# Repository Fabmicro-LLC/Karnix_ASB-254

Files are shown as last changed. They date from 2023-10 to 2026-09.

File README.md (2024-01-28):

# Karnaugh Interactive Extendable ASIC Simulation Board AKA Karnix ASB-254.

## Features:

- RPi3 form factor board with 40pin head connector
- Lattice ECP5 25K FPGA, RISC-V ready
- SRAM 16x256 KBits (512 KB)
- NOR flash 128 MBits for FPGA configs
- EEPROM 1Kbits (128 bytes) for user settings
- Ethernet 10/100Base-TX
- RS-485 transceiver
- HDMI connector directly connected to FPGA
- SPI DAC 4 channels (2 for audio)
- SPI ADC 4 channels + 1 mic in
- 4 keys and 4 LEDs
- 4 pin audio jack connected to DAC/ADC
- Built-in FT2232D based programmer

## Board images

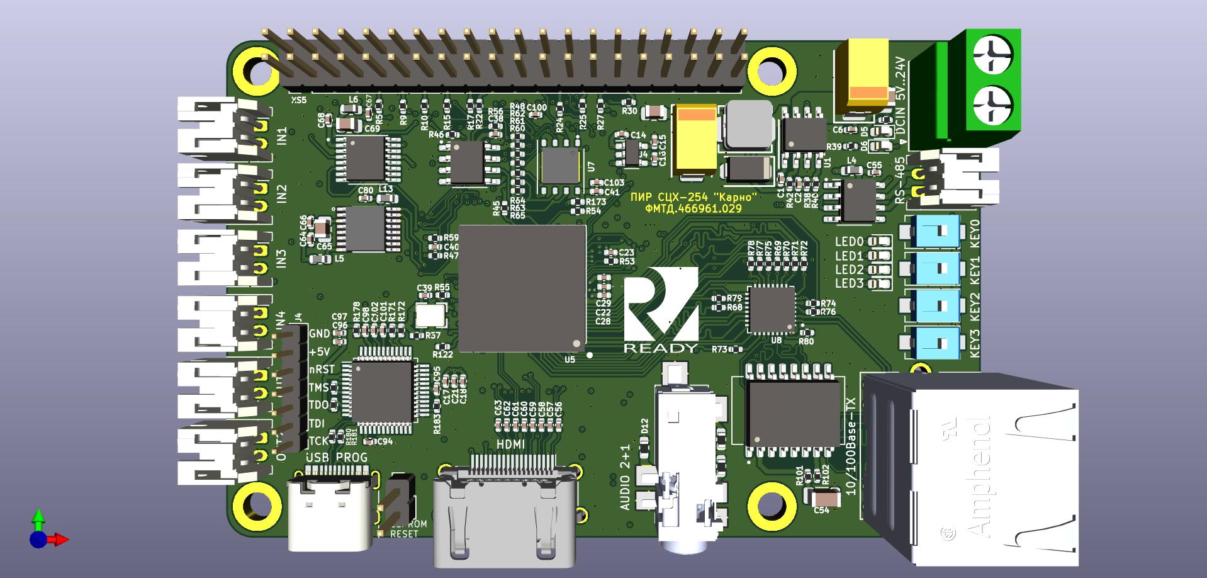
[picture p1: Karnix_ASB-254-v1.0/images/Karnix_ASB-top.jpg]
TOP side


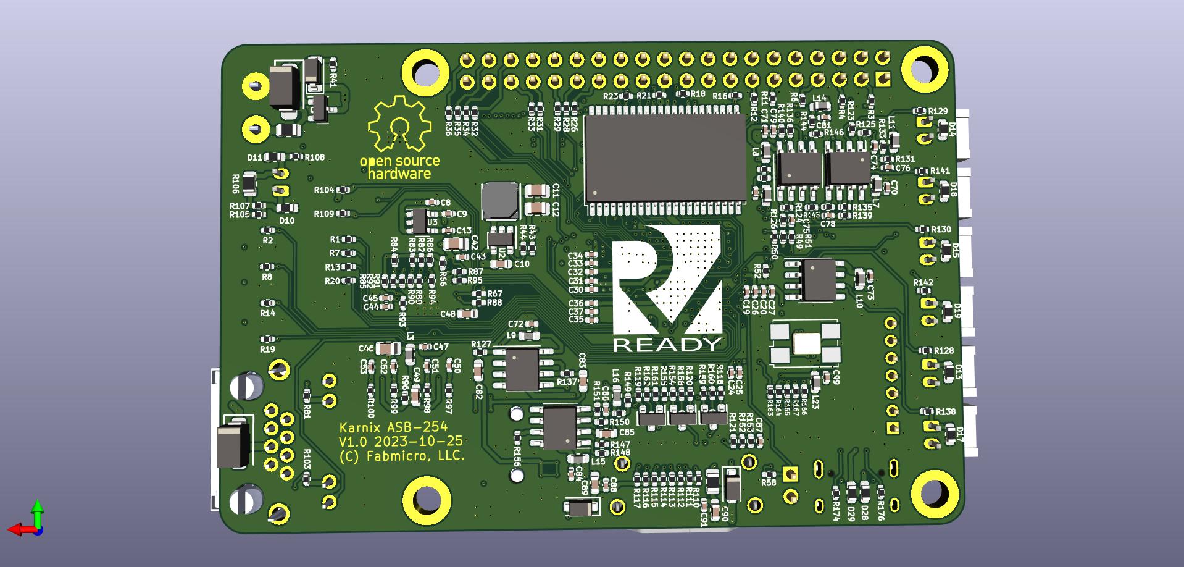
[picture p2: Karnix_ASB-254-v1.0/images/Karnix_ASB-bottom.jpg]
BOTTOM side


# Karnix v1.0 bugs

Version 1.0 appeared to be buggy:
- Ethernet does not work because of wrong power wiring.
- FT2232D IOVCC was wrongly wired to +5V instead of +3V3.
- Some issues with footprints.

## Examples

- Directory **Examples/VexRiscvWithHUB12ForKarnix** contains complete implementation of HUB-12/HUB-75 adapter for LED matrixes written in C running on VexRiscv soft-core. It provides Modbus/UDP interface to corresponding LED matrix.

## Video

https://www.youtube.com/watch?v=xr0pdGuJbXQ

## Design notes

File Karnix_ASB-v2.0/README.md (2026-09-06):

2026-09-01 (DONE)
=================

1. Сократить число портов АЦП и ЦАП до 2+2 (плюс аудио).
2. Сагрегировать линии ЦАП и АЦП каждый в своем идином ращъеме JST 4пин.
3. Добавить тактовый сигнал для NOR Flash памяти.
4. Добавить разъем SD-карты (режим SPI).
5. Перенести кнопки в другое место, высвободить место под USB type A.
6. Добавить USB type A.
7. Добавить SDRAM 64МБ.
8. (-) Добавить сигнал LDAC на ЦАП.

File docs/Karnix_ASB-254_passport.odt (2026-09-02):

Плата разработчика

ПИР СЦХ-254 «КАРНО»

ФМТД.466961.029

вер. 1.x

ПАСПОРТ

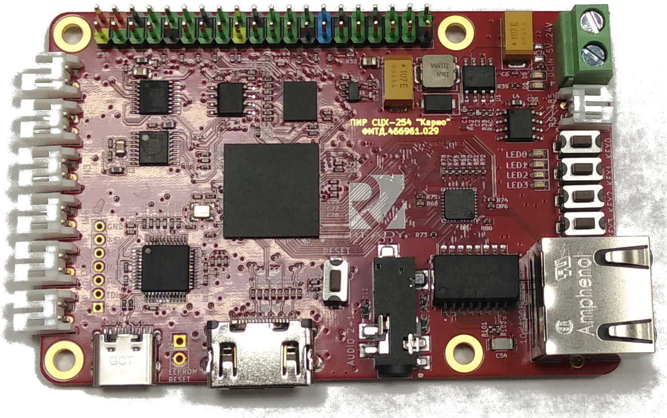
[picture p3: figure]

1. НАЗНАЧЕНИЕ

Плата разработчика "Карно" спроектрована на основе микросхемы ПЛИС Lattice ECP5 и предназначена для синтеза цифровых схем и их тестирования. На плате может быть собран полноценный микроконтроллер для управления промышленными устройствами.

В качестве демонстрации мы синтезировали средствами ПЛИС полноценный микроконтроллер с вычислительным ядром RISC-V (VexRiscV с тактовой частотой 60 МГц), контроллером FastEthernet и контроллером интерфейса HUB75. Через HUB75 к плате может быть подключена светодиодная матрица формата 80x40 (RGB). На ядре RISC-V запускается программное обеспечение реализующее программный протокол Modbus over IP/UDP Modbus/UDP), через который ножно обновлять изображение выводимое на светодиодную матрицу, а также выводить данные на каналы АЦП, т.е. генерировать звук.

Плата ПИР СЦХ-254 "Карно" спроектированная в САПР KiCAD 7 и является полностью открытым проектом (OSHW). Цифровая аппаратура ПЛИС разработана на языке SpinalHDL и синтезирована с помощью open source toolchain Yosis / NextPNR. Программное опеспечения для ядра RISC-V написано на языке C с использованием облегченного TCP/IP стека lwIP. Объём машинного кода - 75КБ, размещается в синтезируемой RAM.

По способу защиты человека от поражения электрическим током плата разработчика «Карно» соответствуют классу III ГОСТ12.2.007.0-75 (сверхнизкое напряжение).

По рабочим условиям применения (в части климатических и механических воздействий) плата разработчика «Карно» удовлетворяет требованиям групп исполнений В4 и L3 ГОСТ12997-84 соответственно.

Конструктивно, плата разработчика «Карно» выполнена в виде печатной платы с четырьмя монтажными отверстиями, предназначенные для монтажа в составе другого изделия или комплекса, по периметру платы располагаются интерфейсные разъемы.

Плата разработчика ПИР СЦХ-254 «Карно» поставляется БЕЗ программного обеспечения.

Ссылки на ресурсы в сети Интернет:

Схема и трассировка платы в САПР KiCAD:

https://github.com/Fabmicro-LLC/Karnix_ASB-254

Демонстрационное программное обеспечение:

https://github.com/Fabmicro-LLC/VexRiscvWithHUB12ForKarnix

Демонстрационное видео:

https://www.youtube.com/watch?v=xr0pdGuJbXQ

2. ТЕХНИЧЕСКИЕ ХАРАКТЕРИСТИКИ

Таблица 1. Технические характеристики

Характеристики вычислительной системы:
Микросхема ПЛИС | Lattice ECP5 25К LUs
Количество вычислительных ядер: | 1
Тактовая частота: | 1028МГц
ОЗУ | 16x256 КБит (512 KБ)
ЭППЗУ | 1кБит
Объем NOR flash | 128МБит
Количество каналов АЦП, разрядность, тип | 5, 12 бит, SPI
Количество каналов ЦАП, разрядность, тип | 4, 12 бит, SPI
Сеть: - FastEthernet - UART | 10/100BaseT RS-485
Число дискретных линий ввода/вывода | 28
Тип дискретных линий ввода/вывода | LVCMOS33
Число кнопок | 4
Число светодиодных индикаторов | 4
Видео | HDMI, прямое соединение с ПЛИС
Аудио | 3.5`` Jack
Электропитание:
Напряжение питания на входе XS1: Напряжение питания на RJ-45 (passive PoE) Напряжение питания на разъеме программатора (USB) | 5 – 24В 5 – 24В 5,5В
Потребляемая мощность: | не более 2Вт
Условия эксплуатации:
Температура: | -40C / +45С
Влажность, не более | 85% при 35С
Габариты - печатной платы - печатной платы с разъемами | 85x56 мм 90x58 мм
Средний срок службы: | 10 лет
Время наработки на отказ: | 10000 часов
Программатор
Встроенный на базе FT2232D - канал 0 - канал 1 | JTAG UART
Интерфейс программатора | USB type C

3. ОРГАНЫ ИНДИКАЦИИ И УПРАВЛЕНИЯ

Плата разработчика ПИР СЦХ-254 «Карно» оснащена двумя светодиодными индикаторами зеленого цвета для индикации состояния линий питания питания и четырьмя светодиодными индикаторами LED0-LED3 зеленого цвета предназначенных для программирования пользователем.

На плате имеется одна кнопка системного сброса «RESET», нажатие на которую приводит к сбросу микросхемы ПЛИС и инициации процесса считывания конфигурации из NOR flash памяти, а так же четыре кнопки KEY0-KEY3 назначение которых определяется пользователем.

4. НАЗНАЧЕНИЕ РАЗЪЕМОВ

Подключение питания, внешних устройств к плате ПИР СЦХ-254 «Карно» осуществляется с помощью разъемов расположенных по периметру платы назначение которых приведено в таблице 2. Ниже приведено схематичное расположение разъемов и их обозначения (вид со строны «TOP»).

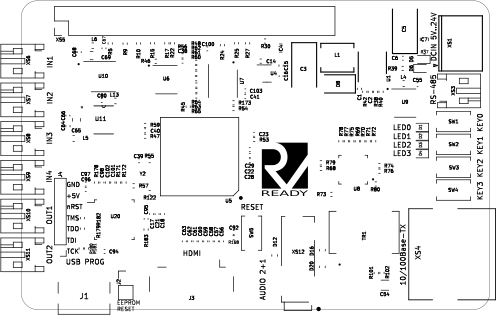
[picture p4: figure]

Рис. 1. Расположение разъемов и их обозначения.

Таблица 2. Назначение разъемов.

Обозначение на плате | Назначение и распиновка разъема
XS1 | Вход питания. Пин 1 — 5-24В, пин 2 — GND.
XS3 | RS-485. Пин 1 — линия А, пин 2 — линия B.
XS6 | Вход АЦП канала 1. Пин 1 — вход (макс 3.3В), пин 2 — GND.
XS7 | Вход АЦП канала 2. Пин 1 — вход (макс 3.3В), пин 2 — GND.
XS8 | Вход АЦП канала 3. Пин 1 — вход (макс 3.3В), пин 2 — GND.
XS9 | Вход АЦП канала 4. Пин 1 — вход (макс 3.3В), пин 2 — GND.
XS10 | Выход ЦАП канала 1. Пин 1 — выход (макс 3.3В), пин 2 — GND.
XS11 | Выход ЦАП канала 2. Пин 1 — выход (макс 3.3В), пин 2 — GND.
XS12 | Аудио вход/выход. Пин 1 — аудио левый канал (ЦАП канал 3) Пин 2 — аудио правый канал (ЦАП канал 4) Пин 3 — аудио вход (АЦП канал 5) Пин 4 — общий (GND).
XS4 | FastEthernet с фукцией passive PoE (пины 4 и 5 - «+», пины 7 и 8 - «-»).
XS5 | Разъем GPIO. Пин 1 и 17 - +3,3В Пин 2 - +5В Пин 6, 9, 14, 20, 25, 30, 34, 39 - «замля» (GND) Остальные пины — линии GPIO, уровень: 3.3В см. схему на рис. 2.
J3 | HDMI, прямое подключение к ПЛИС.
J1 | Разъем программирования через встроенный JTAG программатор (FT2232D)
J4 | Разъем прямого программирования ПЛИС через JTAG. Пин 1 — TCK Пин 2 — TDI Пин 3 — TDO Пин 4 — TMS Пин 5 — RESET Пин 6 — Питание +5В Пин 7 — общий (GND)

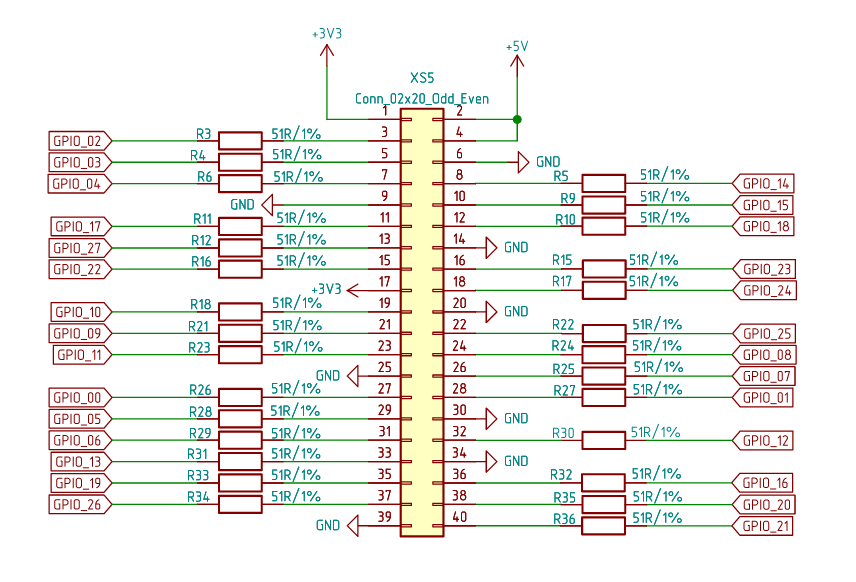
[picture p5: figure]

Рис. 2. Схема цоколевки разъема XS5.

5. КОМПЛЕКТНОСТЬ

Состав комплекта | Количество, шт.
Плата ПИР СЦХ-254 «Карно» | 1
Провод для программирования USB type C | 1
Паспорт | 1

6. УКАЗАНИЯ МЕР БЕЗОПАСНОСТИ
  1. Все отключения или подключения к плате должны осуществляться при выключенных источниках питания с соблюдением полярности.
  2. При эксплуатации платы должны выполняться требования техники безопасности, изложенные в документации на первичные преобразователи, средства измерений и оборудование, в комплекте с которыми она работает.
  1. Изделие имеет открытые низковольтные токоведущие части, попадание влаги или загрязнений в которые может привести к короткому замыканию и повреждению изделия.
7. ПРАВИЛА ТРАНСПОРТИРОВАНИЯ И ХРАНЕНИЯ

1) Изделие должно транспортироваться в условиях, не превышающих заданных предельных условий:

- температура окружающего воздуха -55 …+80 °С;

- относительная влажность воздуха до 95 % при температуре +35 °С.

2) Изделие может транспортироваться авиационным, железнодорожным или автомобильным видами транспорта в транспортной таре при условии защиты от прямого воздействия атмосферных осадков. Не допускается бросание изделия, изгибания или применение торсионной нагрузки.

3) Долгосрочное хранение изделия должно производиться в складских помещениях потребителя и поставщика в следующих условиях:

- температура окружающего воздуха 0 …+50 °С;

- относительная влажность воздуха до 95 % при температуре +35 °С.

- воздух помещения не должен содержать пыли, паров кислот и щелочей, а также газов, вызывающих коррозию.

8. ГАРАНТИЙНЫЕ ОБЯЗАТЕЛЬСТВА

1) Предприятие-изготовитель гарантирует соответствие выпускаемых изделий всем требованиям ТУ на них при соблюдении потребителем условий эксплуатации, транспортирования и хранения.

2) Длительность гарантийного срока устанавливается равной 12 месяцев.

3) Гарантийный срок исчисляется с даты отгрузки (продажи) изделия. Документом, подтверждающим гарантию, является паспорт с отметкой предприятия-изготовителя.

4) Гарантийный срок продлевается на время подачи и рассмотрения рекламации, а также на время проведения гарантийного ремонта силами изготовителя в период гарантийного срока.

9. КОНТАКТЫ ПРОИЗВОДИТЕЛЯ

ООО "Фабмикро"

625048, г. Тюмень, ул. Фабричная, д. 9/5, Российская Федерация.

Тел: +7-3452-591895, info@fabmicro.ru, https://www.fabmicro.ru

10. ОТМЕТКА О ПРОДАЖЕ

Сер. №: _____________, Дата: ______________

Продавец: ____________________ М.П.

____________________________________________________________ ПИР СЦХ-254 “КАРНО” вер. 1.x. Паспорт. Редакция от 03.02.2024 12

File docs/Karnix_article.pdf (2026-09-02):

## Отладочная плата ПИР СЦХ-254 «Карно»

Графов М.В., преподаватель НИУ «МЭИ» ведущий Школы Синтеза Цифровых Схем (https://engineer.yadro.com/chip-design-school/) в кластере «МЭИ» GrafovMV@mpei.ru

Аннотация
Статья посвящена краткому обзору аппаратных средств отладочной платы разработчика «Карно» [1] на базе FPGA серии ECP5 от Lattice Semiconductor, отечественного производителя ООО «Фабмикро» [2]. Рассмотрен состав платы, некоторые схемотехнические особенности, описан, обнаруженный в ходе работы над статьей, схемотехнический недостаток. В конце статьи приведены краткие выводы по возможностям платы, возможные области применения, выявленные достоинства и недостатки, а также полезные ссылки для дальнейшей самостоятельной работы специалистов и начинающих, заинтересованных в использовании данной платы. Введение
Отладочные платы для инженеров, связанных с разработкой устройств на базе FPGA или микроконтроллеров, чаще всего применяются в двух случаях: для начального изучения, используемой на плате FPGA или микроконтроллера, либо для быстрой реализации конкретного проекта, при условии наличия на плате необходимых аппаратных средств. В любом из этих случаев, использование готовых, отладочных плат значительно экономит время и силы, позволяя сконцентрироваться на изучении, либо на разработке текущего проекта, нежели, чем на разработку и сборку самой отладочной платы!
От проприетарного ПО к open source toolchain и Open-source hardware
В случае выбора пути покупки готовой платы, встаёт вопрос предпочтения, той или иной плате из набора существующих на рынке плат, приобретения отладочной платы, и собственно, эксплуатация платы, чему, в свою очередь, может значительно помочь техническая поддержка производителем. Обычно, техническая поддержка заключается в предоставлении производителем примеров кода для периферийных устройств, установленных на плате, документов с описанием портов ввода - вывода GPIO, а также с принципиальной схемой устройства.
На сегодняшний день на рынке предлагается большое количество таких изделий различных производителей и для большого количества микросхем программируемой логики, начиная от простых CPLD и заканчивая сложными FPGA большой ёмкости и SoC. Все они имеют очень разный набор периферийных средств, выпускаются разными производителями, но в подавляющем большинстве случаев их объединяет одно – необходимость наличия проприетарного программного обеспечения! Это значит, что формирующим bit-stream файл для целевой ПЛИС, должен быть софт от производителя самой ПЛИС! Да, бесспорным является тот факт, что существуют бесплатные версии IDE, поддерживающие ограниченный функционал и набор микросхем. Существуют сторонние редакторы HDL и различные вспомогательные программы, приложения, плагины и т.д., но… Как было сказано выше: «…конечным инструментом..» и т.д.! Хорошо это или плохо, вопрос не в этом, но это факт и его никак не оспорить! Ибо внутренняя структура микросхем ПЛИС известна только производителю этой микросхемы, а значит и софт должен быть только этого производителя! Однако, идеология open source не обошла и такую консервативную и закрытую тему, как ПЛИС и существует, как минимум один, производитель микросхем программируемой логики, с (условно) открытой архитектурой и также существует открытое ПО для таких микросхем. Речь идёт о производителе Lattice Semiconductor и открытом программном продукте (open source toolchain) Yosys. На этом месте необходимо сделать небольшой экскурс в историю, что бы понять смысл "условно" открытой архитектуры. Изделия фирмы Lattice, также, проприетарные и внутренняя их структура до недавнего времени была закрыта. Однако, в середине 2010-х небольшая группа исследователей из Германии смогла осуществить "реверс-инжениринг" некоторых из них - сначала модель iCE40, а потом и ECP5. Используя проприетарный тулчейн, они синтезировали большое количество определенных структур и изучали закономерности -как это выглядит в битстриме. Так появился первый open-source синтезатор Yosys и первый плейсей Arachne-pnr. Всю полученную информацию о структуре ПЛИС они сохраняли в базу данных специального формата - ChipDB. После того, как это дело было
опубликовано | на | FOSDEM, | большое | количество | энтузиастов
подхватило её и занялось "реверсингом" ПЛИС других производителей. Сейчас в ChipDB содержится информация о структуре большого количества микросхем ПЛИС разных производителей, в том числе Altera, Xilinx и GOWIN. Вместо
Arachne-pnr | был | написан | другой, | более | универсальный | и | прогрессивный
плейсей - NextPnR. Производители микросхем ПЛИС не стали мешать энтузиастам, а возможно, даже помогают, предоставляя закрытую документацию о структуре своих изделий. Это одна из причин, по которой в среде "опенсорс/опенхард" (OSHW) фирму Lattice любят. Учитывая не самые высокие показатели по месту на рынке, это может быть хорошим маркетинговым ходом для продвижения своей продукции.
В статье не будет обзора микросхем производителя, не будет разбора возможностей и характеристик микросхемы ПЛИС, на которой собрана отладочная плата, и тем более не будет ничего про Yosys. Это темы для других статей и обзоров гораздо большего объема, здесь же будет краткий обзор отладочной платы на базе FPGA от Lattice Semiconductor серии ECP5 и некоторые схемотехнические особенности платы. Желающим глубже погрузиться в эту тематику, можно порекомендовать к прочтению статьи разработчика платы Руслана Залата [3], [4]. Также, целью статьи не является копирование информации о плате с сайта производителя, любой заинтересовавшийся читатель сможет самостоятельно пройти по ссылкам, приведённым ниже, и получить всю информацию от первоисточника, т.е. от разработчика и производителя платы.
Особенности платы ПИР СЦХ-254 «Карно»
Прежде чем начать содержательную часть статьи, необходимо отметить, что плата была предоставлена в кластер «МЭИ» школы синтеза, разработчиком, бесплатно, для ознакомления и дальнейшей работы заинтересованных студентов с Yosys, за что БОЛЬШОЕ СПАСИБО, а также за консультации, предоставленные при написании данной статьи! Плата поддерживается школой синтеза, т.е. на нее портированы некоторые лабораторные работы, поддерживается работа со скриптами школы и синтез в Yosys. Так что же такого особенного и замечательного в этой плате, что её отличает от большого количества других, таковых же, похожих плат?
1. Как уже было указано выше, целевая FPGA от Lattice Semiconductor, серии ЕСР5 поддерживается open source toolchain Yosys, что встречается крайне редко!
2. Отечественный производитель – ООО «Фабмикро». И это не просто контрактное производство плат, это разработчик схемы, ПО, сборка печатных плат на специализированных, промышленных автоматах, а не ручной монтаж. Т.е. это не домашняя разработка энтузиаста open source toolchain, а полноценное промышленное изделие, начиная от децимального номера на штампе конструкторской документации и заканчивая фирменной упаковкой и паспортом изделия с печатью организации и гарантийным сроком! Визуально, при осмотре платы, дефектов сборки не обнаружено. Единственное, что омрачает положительные эмоции от обладания данной платой, это то, что производитель лишил нас такой приятной процедуры, как отмывка флюса на плате... Вспомните, счастливые обладатели OMDAZZ – ов и RZRD и т.д. и тем более no name of China, много спирта извели на отмывку!?

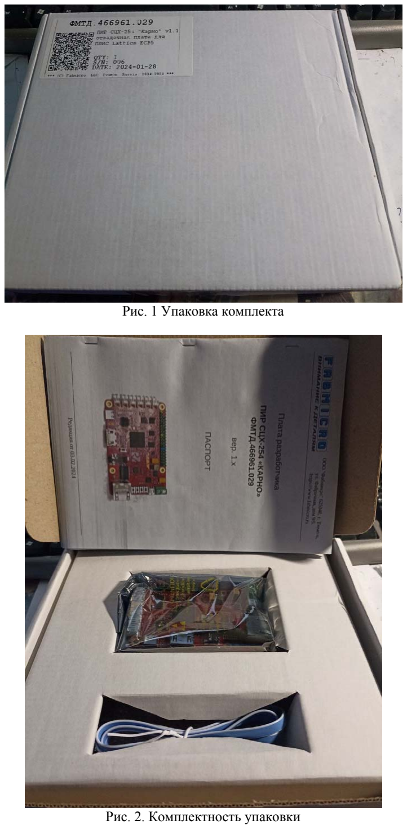
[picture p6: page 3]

Рис. 1 Упаковка комплекта

Рис. 2. Комплектность упаковки

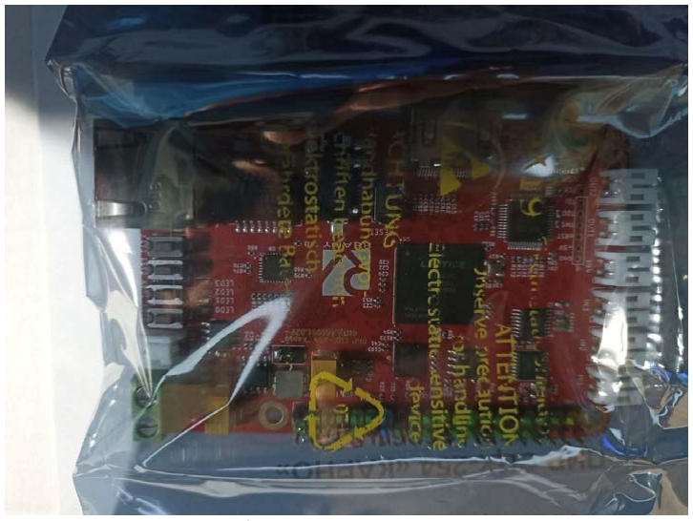
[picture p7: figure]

Рис. 3. Упаковка самой платы

3. Полноценная техническая поддержка проекта на github [5]
4. Проект платы не только выполнен на ПЛИС с открытой архитектурой, поддерживается открытым ПО Yosys, но и разработка выполнена в открытом ПО для проектирования печатных плат – KiCad EDA. Все исходные файлы схем и плат доступны в репозитории поддержки. Любой желающий, при наличии соответствующей квалификации, может самостоятельно повторить этот проект.
5. Форм-фактор платы – Raspberry Pi 3. Не большая плата, «размером с кредитку».
6. Широкий диапазон питающих напряжений 5-24 В, что позволяет запитывать плату от постоянного напряжения 24 В, используемого в промышленной автоматике.
7. Возможность покупки физ. лицами за наличный расчёт через торговую площадку «OZON», а также безналичным путём, оплатой счёта юридического лица, что важно для возможности закупки коммерческим и бюджетным организациям!
Состав аппаратных средств платы

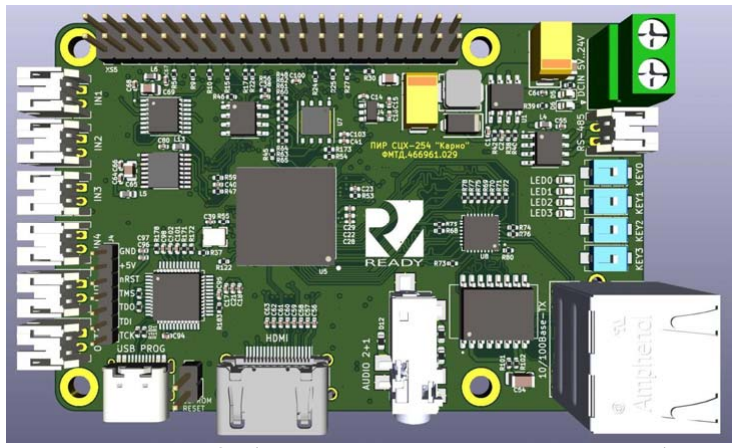
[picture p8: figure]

Рис. 4 Слой TOP (верхняя сторона установки элементов)

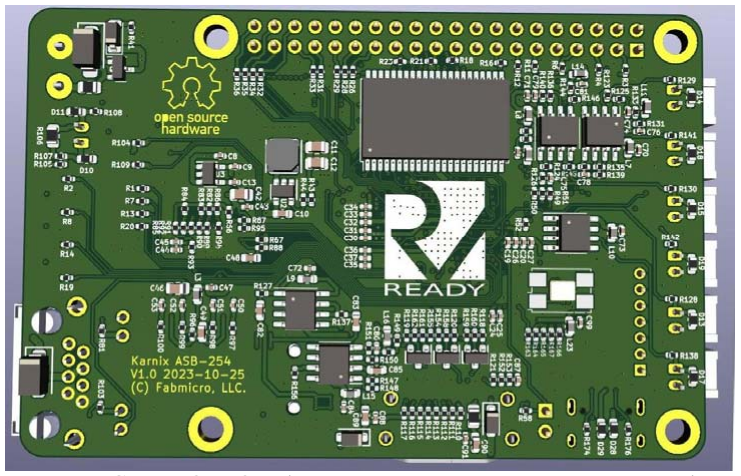
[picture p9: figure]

Рис. 5 Слой BOTTOM (нижняя сторона установки элементов)

На Рис. 4 и 5 приведен внешний вид платы начальной версии V1.0. На сегодняшний день в репозитории есть уже V1.1 и V1.2 и еще разработчик планирует новый релиз платы с устранением обнаруженных недостатков. Как видно по Рис. 1, на обзоре релиз платы V1.1

FPGA Lattice ECP5
Основа платы, целевая ПЛИС - ECP5 семейства, LFE5U-25 в корпусе BGA-256. Имеет "на борту" 24К LUTs, различные виды памяти - системная блочная, 56 блоков по 18 кБит, встроенная 1,008 кБит, распределенная 194 кБит. Имеются 28 умножителей 18х18, два канала PLL/DLL, поддержка большого числа стандартов ввода-вывода, DDR2/DDR3, синхронизация с высокоскоростными АЦП, ЦАП. Сравнивать по производительности с другими типами ПЛИС других производителей нет смысла, так как это зависит от конкретного описания и теста.. Если попытаться грубо оценить относительно других семейств ПЛИС, например INTEL/ALTERA, то можно сказать что это уровень младших чипов семейства CycloneIII - CycloneIV, т.е. EP3C5-EP3C25, или EP4CE6-EP4CE22. Хотя, технология изготовления ECP5 - 40 нм, что меньше чем у "циклонов", а значит быстрее и меньше потребляет мощности. Это FPGA младшей/средней ценовой категории и производительности. Что касается тестов, то для оценки возможностей разработчиком был реализован проект SoC (СнК), на базе VexRiscV, работающим на частоте 65 МГц, с небольшим I$ и D$, и набором различной периферии (CGA через HDMI, Ethernet...) [6].

Программатор
Программирование целевой ПЛИС осуществляется JTAG интерфейсом через USB порт. Это реализовано при помощи специализированной микросхемы, осуществляющей функции моста USB-COM, FT2232D от фирмы FTDI. В ней содержится два аппаратных канала-моста USB-COM, один из которых выполняет программную эмуляцию JTAG интерфейса. Второй же канал последовательного порта доступен как пользовательский COM порт и может быть использован для обмена данными с ПК. Таким образом, одним кабелем, подключенным к USB порту ПК, осуществляется питание платы, загрузка битстрим файла и обмен данными по последовательному порту! Для работы с платой внешний программатор НЕ НУЖЕН!!! Однако, есть возможность подключения внешнего программатора, для чего на плате установлен разъём J4.

Микросхемы памяти
На плате присутствуют энергонезависимые устройства и статическая память. К энергонезависимым относятся: EEPROM AT24C01 объёмом 1 КБит (128 Байт), для хранения пользовательских данных, интерфейс – IIC (I²
C), а также NOR flash W25Q128 объёмом 128 Мбит для хранения конфигурации FPGA, интерфейс – SPI. Наибольший интерес тут представляет SRAM – K6R4016. Да, это fully static RAM, организацией 256Кх16 и временем доступа 10 нс! А это означает, что не нужен драйвер динамической памяти, это означает малое время доступа к памяти, отсутствие latency, а как следствие применение как память данных в быстрых вычислителях, как СОЗУ и ОЗУ в однотактных процессорах, как L0, L1 Cashe и т.д., в зависимости от решаемой задачи.

Интерфейсы
Несмотря на малые размеры платы, в ней есть несколько различных по сложности и типу взаимодействия с пользователем интерфейсов. Начать можно с самого простого - на плате присутствуют 5 тактовых кнопок без фиксации KEY[3:0], FPGA_RESET и 4 дискретных светодиода LED[3:0]. Все кнопки нормально разомкнутые, имеют "Pull-Down" подтяжку. Это значит, что если кнопка не нажата, то на входах KEY[3:0] и FPGA_RESET присутствует уровень лог. 0, при нажатии на кнопку формируется уровень лог. 1, так как кнопка подключена к питанию +3,3В. Светодиоды LED[3:0] включены по схеме с общим катодом, что означает то, что для засветки светодиода надо выставить уровень лог. 1 на выходы LED[3:0]. На плате нет семисегментных светодиодных индикаторов, так горячо любимых всеми производителями отладочных плат. Возможно, этот факт будет негативно воспринят начинающими, так как применение этих индикаторов, весьма наглядно на начальных этапах обучения цифровому синтезу. Однако, этот недостаток легко устраним при помощи внешнего модуля на микросхеме TM1638, в различных ее применениях, с разными числом дополнительных кнопок и светодиодов. Модуль недорогой и легко приобретается. Будет хорошим учебным проектом, написание модуля на языке System Verilog для подключения к плате! Более того, в примерах школы синтеза цифровых микросхем это уже реализовано! Поэтому, малое количество кнопок и светодиодов и отсутствие семисегментых индикаторов, не являются негативным фактором при использовании данной платы! Это же утверждение справедливо и для других подобных модулей, например модули от Sipeed, для уже широко известных FPGA GOWIN. Модуль можно подключить к плате через еще один интерфейс платы - 40 пиновый разъем портов ввода-вывода общего назначения. Это пользовательские выводы FPGA, программируемые пользователем по своему усмотрению. На разъёме присутствуют 28 портов ввода-вывода GPIO[27:0], сигналы питания +5В, +3,3В и "земля". Например, для подключения модуля индикации и кнопок на TM1638, достаточно двух сигнальных выводов и питание. Модуль подключается по последовательному интерфейсу SPI. Аналогично, возможно подключение любых других внешних цифровых устройств, при наличии свободных портов GPIO, достаточной скорости обмена по этим портам и соответствии стандартов ввода-вывода устройств и выводов FPGA.
Как было уже сказано выше, модуль имеет возможность подключения к последовательному порту ПК, через имеющийся на плате двухканальный мост USB-COM. Реализация COM интерфейса программная, в данном случае это задача пользователя. Номер COM порта в ПК может быть разный, зависит от производителя "материнской платы" ПК, версии BIOS и драйверов на FT2232D. Обычно это COM3, COM4, но могут быть и другие из списка "виртуальных" портов (т.е. не COM1 - COM2). Последовательный порт очень широко применяется при передачи небольших объемов данных на малых скоростях (хотя современные чип-сеты "материнсикх плат" поддерживают скорости обмена до единиц МБит!) с использованием стандартных терминальных программ, что позволяет использовать этот механизм без написания своих сложных приложений!
На плате есть еще один последовательный интерфейс! Но, он не предназначен для подключения к COM портам ПК, так как имеет физический уровень RS485 стандарта! Это протокол последовательного обмена для промышленных применений, так как данные
передаются | дифференциальной | парой | сигналов, | что | значительно | повышает
помехоустойчивость и позволяет иметь длину линии связи в сотни метров! Таким образом, наличие RS485 на плате, позволяет использовать её как промышленный контроллер! Возможно и подключение к ПК через этот канал, но для этого понадобится переходник RS485-RS232, который также легко приобретается и доступен!
Для реализации видеоприложений и подключения к мониторам на плате предусмотрен HDMI разъём! Разъём подключен напрямую к выводам FPGA через разделительные конденсаторы. Используются дифференциальные пары при передаче сигналов, что необходимо будет указать в проекте в свойствах портов ввода - вывода. Существуют и open-sourse решения для HDMI, как например вот это [7]. Также, в группе по портированию примеров на платы школы синтеза, есть такое же рабочее решение HDMI для этой платы и возможно, оно появится в лабораторных работах. Как было указано выше, разработанная СнК включает в себя драйвер CGA дисплея на HDMI.
И в заключение, последний интерфейс платы - Ethernet 10/100Base-TX. Он реализован установкой на плату трансивера физического уровня LAN8710A от Microcip. Также присутствует разделительный трансформатор и разъём RJ45 для подключения стандартными патч-кордами. Реализация протоколов, будь то TCP/IP или ModBus over IP -пользовательская программная.

Аналоговая часть Весьма редкое явление - наличие полноценной аналоговой части, в виде предусилителей и

отдельных дискретных АЦП - ЦАП. На данной плате присутствуют 8 канальные АЦП и ЦАП. АЦП - ADC128S052. Это 12 битный, 8 канальный, SAR ADC от Texas Instruments. Так как это SAR ADC, то больших скоростей преобразования ожидать не стоит, и для данной микросхемы это 200 - 500 kSPS, что вполне достаточно для аудиоприложений или оцифровки датчиков промышленной автоматики не высокой точности, так как разрешение 12 бит не подходит под определение "метрологического" АЦП, хотя вопрос тут уже в конкретной задаче и точности её решения. ЦАП - AD5328. Это 12 битный, 8 канальный, STRING-DAC (с цепочкой резистивных делителей). На плате присутствуют дискретные разъемы для 4 аналоговых входов и двух аналоговых выходов и комбинированный аудиоразъем типа jack 3,5 мм, на который выведены еще два аналоговых выхода и вход микрофона. Таким образом, на плате имеется 4 аналоговых входа, вход микрофона и 4 аналоговых выхода, подключенные к разного типа разъемам. Что касается входного динамического диапазона и коэффициента преобразования, то тут есть особенность.. Так как входные ОУ LM258 питаются однополярным питанием, то в районе низких входных напряжений может быть завышенная нелинейность коэффициента усиления. В описании на LM258 явно не указано, что тип входа и выхода поддерживается "RAIL to RAIL" хотя и указано что "..Differential input voltage range equal to the power supply voltage ". В процессе обсуждения статьи, разработчик выполнил симуляцию входного каскада, результаты которой приведены в репозитории [8]. Для входов IN1 - IN4 линейный участок находится в диапазоне 0,07 - 6,5 В, LSB - 1,6 мВ. Входной усилитель - инвертирующий! Это все необходимо учитывать, в случае применения АЦП для оцифровки каких либо датчиков. Микрофонный вход имеет коэффициент усиления порядка 840, что может быть не очень приемлемо для каких либо микрофонов, что разработчик подтверждает и в следующем релизе платы, возможно будет доработка для увеличения коэффициента передачи до 2000. На входе микрофона присутствует постоянное смещение равное половине питания, т.е. 1,65 В. Следует заметить, что наличие микрофонного аналогового входа на цифровой плате с FPGA или микронтроллером встречается весьма редко, так как сейчас возможно применение сразу цифровых микрофонов, с интерфейсом I²
S, что в школе синтеза сделано и работает на всех платах. Так что, если кому то понадобится качественный микрофонный вход, то лучше воспользоваться этим решением.
В процессе написания статьи и анализа принципиальной схемы включения ЦАП был обнаружен один недостаток - не подключенный вход ~LDAC ЦАП, т.е. первый вывод U11. Ошибка не является критичной, так как ЦАП имеет режим автозащёлкивания данных по последнему тактовому сигналу и тесты в репозитории все рабочие и ЦАП там работает именно в этом режиме. Подключение ~LDAC необходимо, в случае если требуется одновременное, синхронное обновление данных на выходе ЦАП по какому либо внешнему сигналу, подаваемому на вход ~LDAC. Это необходимо при формировании каких либо синхронных многоканальных последовательностей или когерентных аналоговых сигналов, например при формировании квадратурных составляющих сигналов. Очевидно, что это очень узкоспециализированная задача, но если кому это понадобиться делать на версиях платы до V1.2, то придется самостоятельно соединить 1 вывод U11 с каким либо GPIO на выходном разъёме. Разработчик об этом недостатке знает и в следующем релизе платы этот недостаток будет устранён!
Заключение
Рассмотренная плата, в силу своих особенностей, может быть интересна специалистам разных уровней квалификации и применяться для разных задач. Плата может представлять интерес начинающим, делающим первые шаги в цифровом синтезе, так как поддерживается школой синтеза, примеры школы портированы на эту плату. Недостаток в виде малого числа кнопок и светодиодов и отсутствия семисегментных индикаторов легко устранятся приобретением модуля на TM1638. Плата просто незаменима для энтузиастов занимающихся изучением и продвижением open-source. Наличие промышленных интерфейсов и аналоговая часть, после её доработки, могут позволить использовать плату как промышленный контроллер, например для ввода стандартных аналоговых сигналов (токов 0-5, 0-20, 4-20 мА), а наличие портированого RISC-V ядра позволит делать обработку сигналов и подключать плату к другому хосту по Ethernet. Возможностей и приложений много, все зависит от конкретной задачи. Возможно, мы увидим разные релизы платы под применение в идеологии configurable Input Output (cRio от National Instruments), или это будет промышленный контроллер для оцифровки стандартных датчиков и сигналов, а может с развитием движения OSHW плата будет востребована в образовательных целях и учреждениях. Единственно, возможно, существенным недостатком платы, может быть её цена. На момент написания статьи, относительная стоимость платы была равна 2,5 - 3 OMDAZZ или одна DE10-Lite. Это может быть критично для начинающих, ибо они предпочтут более "раскрученную" ALTER-у и QUARTUS, чем малоизвестный Lattice и Yosys, тем более, что для начинающих дешёвый OMDAZZ выглядит предпочтительнее! Но по набору аппаратных средств, установленных на плате, она может быть весьма интересна и востребована! К тому же, следует учитывать реалии отечественного производства, а точнее необходимость закупки импортных комплектующих. В любом случае, появление таковой платы, это весьма знаковое и положительное событие!
Ссылки
[1] Отладочная плата ПИР СЦХ-254 «Карно» https://www.fabmicro.ru/products/125.html
[2] ООО «Фабмикро» https://www.fabmicro.ru/
[3] Статья Руслана Залата, часть 1 https://habr.com/ru/articles/801191/
[4] Статья Руслана Залата, часть 2 https://habr.com/ru/articles/802127/
[5] https://github.com/Fabmicro-LLC/Karnix_ASB-254
[6] https://github.com/Fabmicro-LLC/VexRiscvWithKarnix
[7] https://github.com/hdl-util/hdmi[8]https://github.com/Fabmicro-LLC/Karnix_ASB-254/tree/master/Karnix_ASB-254-v1.2/simulation (https://github.com/Fabmicro-LLC/Karnix_ASB-254/tree/master/Karnix_ASB-254-v1.2/simulation)

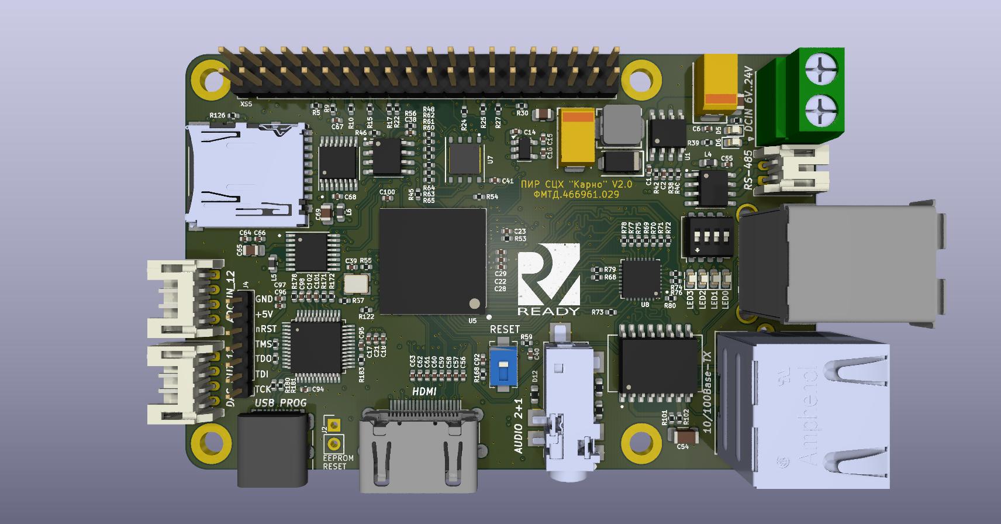
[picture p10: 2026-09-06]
Karnix_ASB-v2.0/images/Karnix_ASB-top.jpg

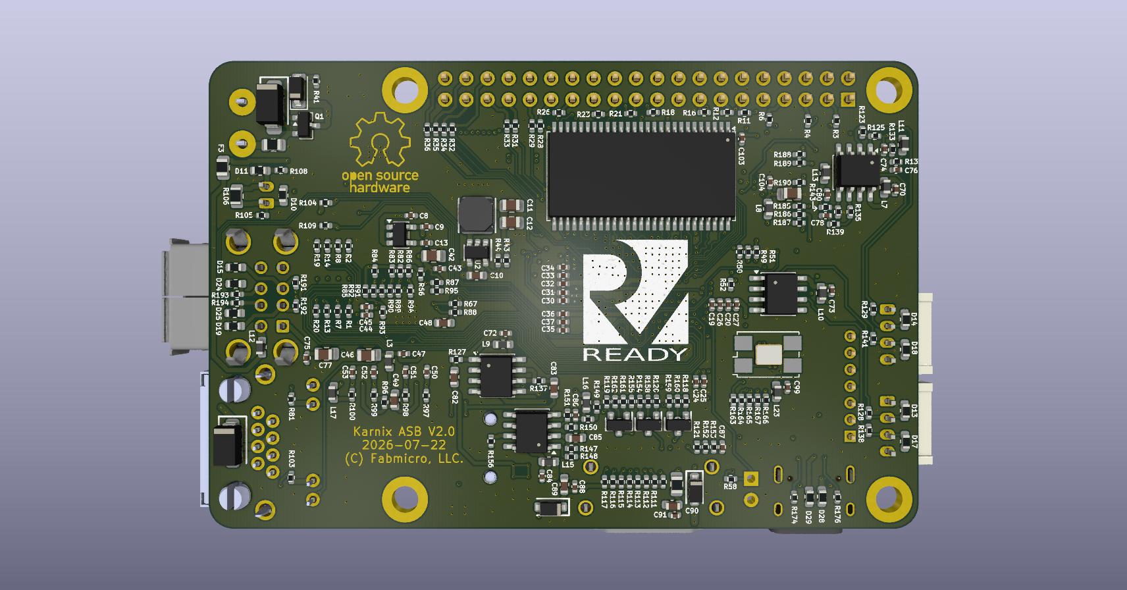
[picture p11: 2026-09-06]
Karnix_ASB-v2.0/images/Karnix_ASB-bottom.jpg

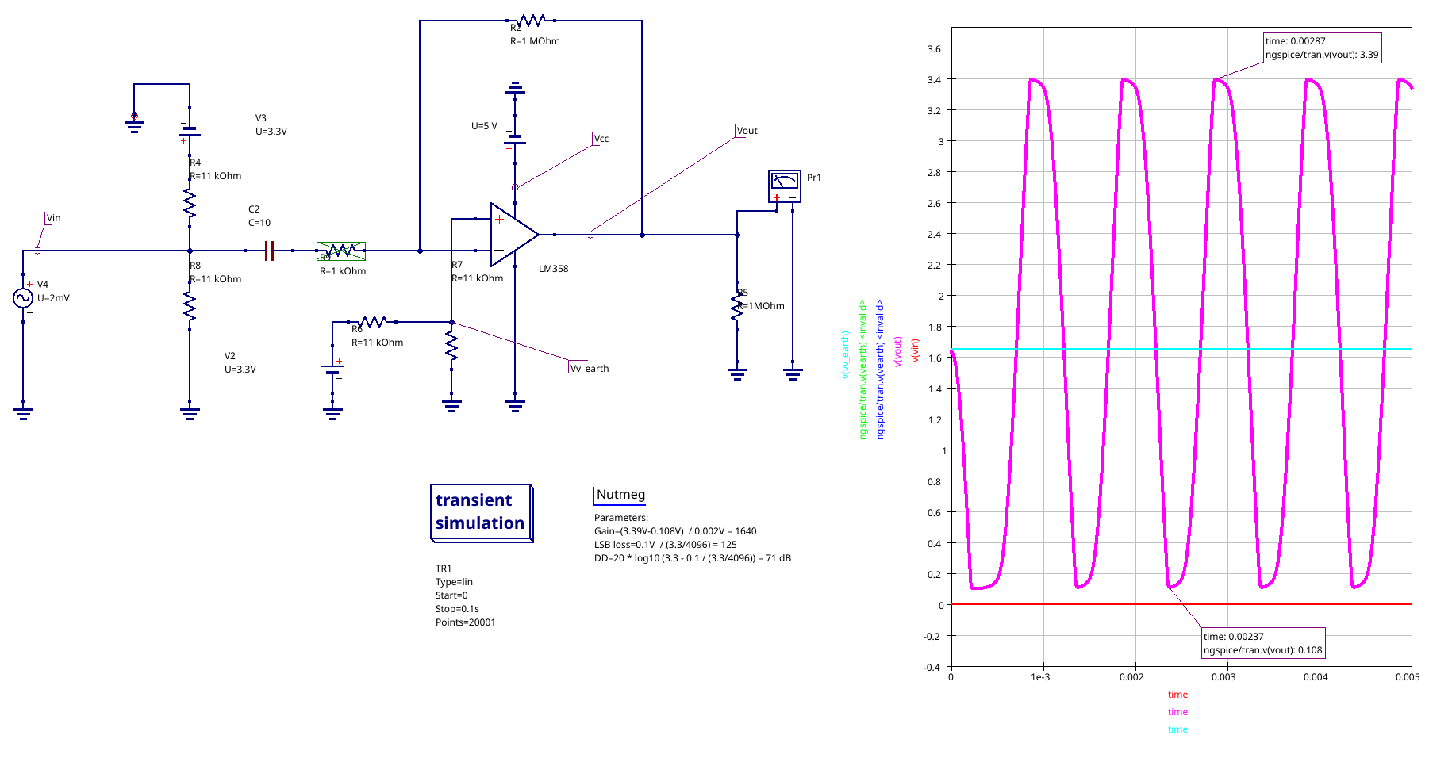
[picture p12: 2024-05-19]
Karnix_ASB-254-v1.2/simulation/ADC_IN_MIC.png

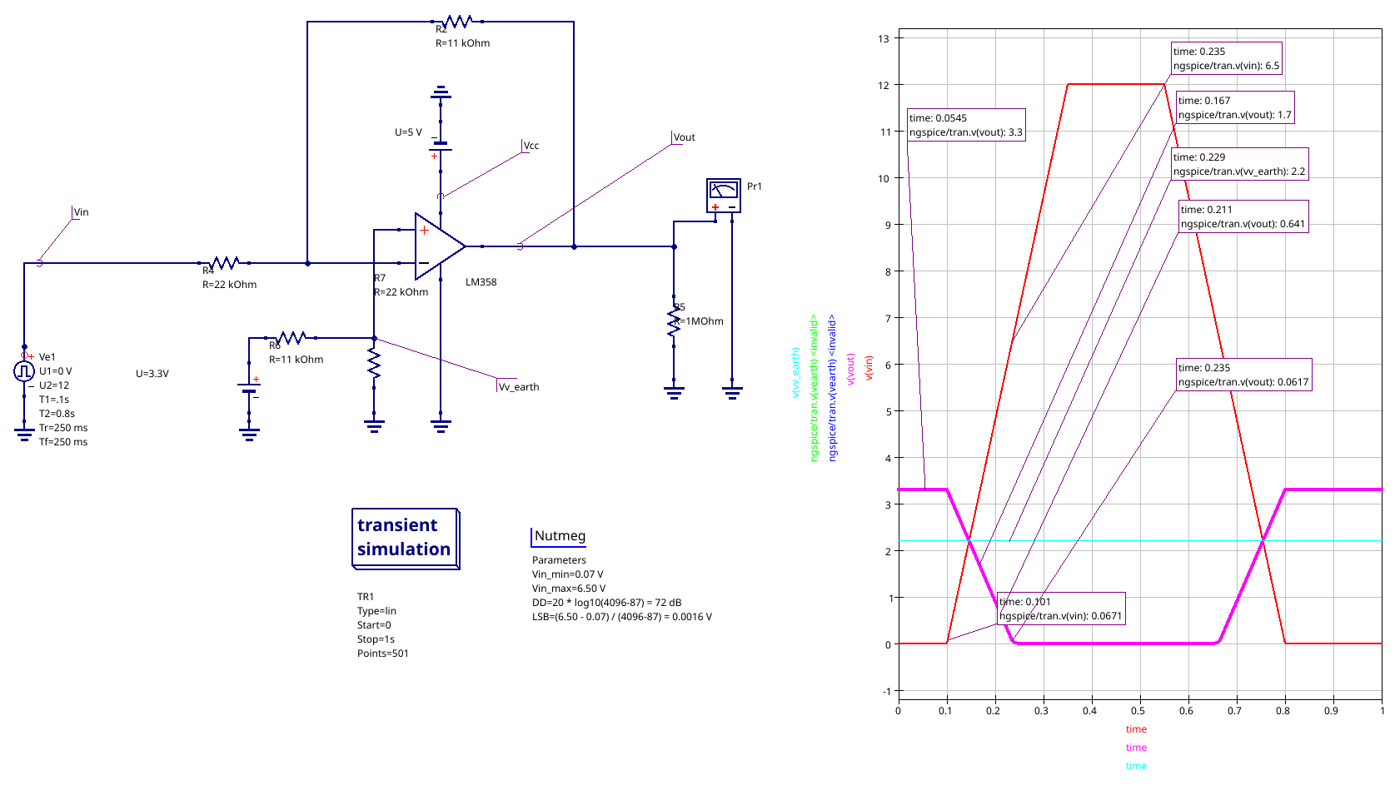
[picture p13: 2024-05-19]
Karnix_ASB-254-v1.2/simulation/ADC_IN_1234.png

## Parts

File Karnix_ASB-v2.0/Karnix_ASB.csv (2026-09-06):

# | Reference | Qty | Value | Footprint | DNP
1 | C1 | 1 | 3.3nF/50V | Fabmicro:C_0402_1005Metric
2 | C2 | 1 | 560pF/50V | Fabmicro:C_0402_1005Metric
3 | C3, C5 | 2 | 100uF/25V | Fabmicro:CP_EIA-7343-43_Kemet-X
4 | C4, C11, C12, C42, C46, C65, C69 | 7 | 22uF/10V | Capacitor_SMD:C_0805_2012Metric
5 | C6, C32, C34, C35, C37, C38, C39, C40, C41, C43, C44, C47, C55, C56, C57, C58, C59, C60, C61, C62, C63, C66, C67, C68, C70, C72, C73, C76, C80, C84, C86, C88, C91, C92, C94, C95, C96, C97, C98, C99 | 40 | 0.1uF/50V | Capacitor_SMD:C_0402_1005Metric
6 | C7 | 1 | DNM | Capacitor_SMD:C_0805_2012Metric
7 | C8, C9, C14, C15, C64, C87 | 6 | 1uF/16V | Fabmicro:C_0402_1005Metric
8 | C10, C48, C82, C83, C85, C89, C90 | 7 | 10uF/10V | Capacitor_SMD:C_0603_1608Metric
9 | C13, C16, C74, C78 | 4 | 0.01uF/50V | Capacitor_SMD:C_0402_1005Metric
10 | C17, C18, C19, C20, C21, C22, C23, C24, C25, C26, C27, C28, C29, C30, C31, C33, C36, C100, C103 | 19 | 4.7uF/6.3V | Capacitor_SMD:C_0402_1005Metric
11 | C45 | 1 | 4.7uF/6.3V | Fabmicro:C_0402_1005Metric
12 | C49 | 1 | 0.47uF/50V | Capacitor_SMD:C_0603_1608Metric
13 | C50, C51, C52, C53 | 4 | 15pF/50V | Fabmicro:C_0402_1005Metric
14 | C54 | 1 | 1000pF/100V | Capacitor_SMD:C_1206_3216Metric
15 | C71 | 1 | 22uF/25V | Fabmicro:C_0805_2012Metric_slim
16 | C75, C104 | 2 | 0.1uF/50V | Fabmicro:C_0402_1005Metric
17 | C77 | 1 | 22uF/25V | Capacitor_SMD:C_0805_2012Metric
18 | C101, C102 | 2 | 27pF/50V | Fabmicro:C_0402_1005Metric
19 | D1, D2, D3, D4, D5, D6 | 6 | FYLS-0603PGC | LED_SMD:LED_0603_1608Metric
20 | D7 | 1 | BZV55-B10 | Fabmicro:D_SOD-80
21 | D8, D23 | 2 | STPS2L40AF | Fabmicro:D_SMA_FLAT
22 | D9 | 1 | SMAJ40CA | Fabmicro:D_SMA
23 | D10, D11, D12, D13, D14, D15, D16, D17, D18, D19, D20, D24, D25, D28, D29 | 15 | PGB1010603NRHF | Fuse:Fuse_0603_1608Metric
24 | D21, D22 | 2 | CRS08 | Fabmicro:D_SOD-123F
25 | F1, F2, F3 | 3 | 0805L100WR | Fuse:Fuse_0805_2012Metric
26 | H1, H2, H3, H4 | 4 | MountingHole | Fabmicro:MountingHole_3.2mm_M3_ISO7380_NoPad
27 | J1 | 1 | USB_C_Receptacle_USB2.0 | Fabmicro:USB_C_Receptacle_HRO_TYPE-C-31-M-12
28 | J2 | 1 | EEPROM RESET | Fabmicro:PinHeader_1x02_P2.54mm_Vertical
29 | J3 | 1 | HDMI_A_1.4 | Fabmicro:HDMI_A_Amphenol_10029449-x01xLF_Horizontal
30 | J4 | 1 | Conn_01x07 | Connector_PinHeader_2.00mm:PinHeader_1x07_P2.00mm_Vertical
31 | L1 | 1 | 10uH/2.3A | Fabmicro:IHLP-2020
32 | L2 | 1 | 2.2uH/2.5A | Fabmicro:Murata_LQH44PN
33 | L3, L4, L5, L6, L7, L8, L9, L10, L11, L12, L13, L15, L16, L17, L23 | 15 | 330R/1.2A | Inductor_SMD:L_0603_1608Metric
34 | Q1 | 1 | AO3401A | Package_TO_SOT_SMD:SOT-23
35 | Q2, Q3, Q4 | 3 | DMN3730 | Fabmicro:SOT-23
36 | R1, R7, R13, R20 | 4 | 220R/1% | Fabmicro:R_0402_1005Metric
37 | R2, R8, R14, R19, R41, R45, R46, R48, R49, R50, R51, R52, R56, R57, R58, R59, R60, R61, R62, R64, R65, R67, R82, R83, R86, R87, R88, R91, R92, R93, R122, R152 | 32 | 10K/1% | Fabmicro:R_0402_1005Metric
38 | R3, R4, R5, R6, R9, R10, R11, R12, R15, R16, R17, R18, R21, R22, R23, R24, R25, R26, R27, R28, R29, R30, R31, R32, R33, R34, R35, R36 | 28 | 51R/1% | Fabmicro:R_0402_1005Metric
39 | R37, R121, R154, R160, R162, R174, R176 | 7 | 5.1K/1% | Resistor_SMD:R_0402_1005Metric
40 | R38 | 1 | 33K/1% | Fabmicro:R_0402_1005Metric
41 | R39 | 1 | 3K/1% | Fabmicro:R_0402_1005Metric
42 | R40 | 1 | 10.5K/1% | Fabmicro:R_0402_1005Metric
43 | R42 | 1 | 47K/1% | Fabmicro:R_0402_1005Metric
44 | R43 | 1 | 15K/1% | Fabmicro:R_0402_1005Metric
45 | R44 | 1 | 18K/1% | Fabmicro:R_0402_1005Metric
46 | R53, R54, R79 | 3 | 510R/1% | Fabmicro:R_0402_1005Metric
47 | R55, R68, R69, R70, R71, R72, R73, R74, R75, R76, R77, R78, R155 | 13 | 110R/1% | Fabmicro:R_0402_1005Metric
48 | R63 | 1 | 1K/1% | Fabmicro:R_0402_1005Metric
49 | R66, R118, R119, R120, R159, R161 | 6 | 1.5K/1% | Fabmicro:R_0402_1005Metric
50 | R80 | 1 | 12.1K/1% | Fabmicro:R_0402_1005Metric
51 | R81, R103 | 2 | 330R/1% | Fabmicro:R_0402_1005Metric
52 | R84, R85, R89, R90, R94, R95 | 6 | DNM | Fabmicro:R_0402_1005Metric
53 | R96, R97, R98, R99, R100, R110, R111, R112, R113, R114, R115, R116, R117 | 13 | 49.9R/1% | Fabmicro:R_0402_1005Metric
54 | R101, R102 | 2 | 75R/1% | Fabmicro:R_0402_1005Metric
55 | R104, R105, R108, R109, R171, R172, R179, R183 | 8 | 10K/1% | Resistor_SMD:R_0402_1005Metric
56 | R106 | 1 | 120R/1% | Resistor_SMD:R_0805_2012Metric
57 | R123, R131, R135, R143, R149, R150, R151, R157 | 8 | 11K/1% | Resistor_SMD:R_0402_1005Metric
58 | R125, R139, R148 | 3 | 51R/1% | Resistor_SMD:R_0402_1005Metric
59 | R126, R185, R186, R187, R188, R189, R190, R191, R192, R193, R194 | 11 | 22R/1% | Fabmicro:R_0402_1005Metric
60 | R127, R128, R137, R138, R153, R166, R168, R180, R181 | 9 | 22R/1% | Resistor_SMD:R_0402_1005Metric
61 | R129, R133, R141, R145, R156 | 5 | 22K/1% | Resistor_SMD:R_0402_1005Metric
62 | R147 | 1 | 1M/1% | Resistor_SMD:R_0402_1005Metric
63 | R158 | 1 | 27K/1% | Fabmicro:R_0402_1005Metric
64 | R163, R164, R165, R167 | 4 | 0R | Resistor_SMD:R_0402_1005Metric
65 | R178 | 1 | 510R/1% | Resistor_SMD:R_0402_1005Metric
66 | R182 | 1 | 1.5K/1% | Resistor_SMD:R_0402_1005Metric
67 | SW1 | 1 | SW_DIP_x04 | Button_Switch_SMD:SW_DIP_SPSTx04_Slide_Copal_CHS-04A_W5.08mm_P1.27mm_JPin
68 | SW5 | 1 | SW_Push | Button_Switch_SMD:SW_SPST_EVQPE1
69 | TR1 | 1 | SM13126PEL | Fabmicro:SM13126PEL
70 | U1 | 1 | ST1S14 | Fabmicro:HSOIC-8_3.9x4.9mm_P1.27mm
71 | U2 | 1 | TLV62565DBVT | Fabmicro:SOT-23-5
72 | U3 | 1 | RS3236-2.5YF5 | Package_TO_SOT_SMD:SOT-23-5
73 | U4 | 1 | RS3236-3.3YF5 | Package_TO_SOT_SMD:SOT-23-5
74 | U5 | 1 | LFE5U-25F-BG256C | Fabmicro:BGA256C80P16X16_1400X1400X170
75 | U6 | 1 | AT24C01C-SSHM | Fabmicro:SOIC-8_3.9x4.9mm_P1.27mm
76 | U7 | 1 | W25Q128JVPIQ | Fabmicro:WSON-8-1EP_6x5mm_P1.27mm_EP3.4x4.3mm
77 | U8 | 1 | LAN8710AI | Fabmicro:QFN-32-1EP_5x5mm_P0.5mm_EP3.3x3.3mm
78 | U9 | 1 | MAX487ECSA+ | Fabmicro:SOIC-8_3.9x4.9mm_P1.27mm
79 | U10 | 1 | ADC128S052CIMT | Fabmicro:TSSOP-16_4.4x5mm_P0.65mm
80 | U11 | 1 | AD5328BRUZ | Fabmicro:TSSOP-16_4.4x5mm_P0.65mm
81 | U12, U14, U15, U16 | 4 | LM258A | Package_SO:SO-8_3.9x4.9mm_P1.27mm
82 | U20 | 1 | FT2232D | Fabmicro:LQFP-48_7x7mm_P0.5mm
83 | U21 | 1 | MT48LC32M16A2TG-75 | Package_SO:TSOP-II-54_22.2x10.16mm_P0.8mm
84 | XS1 | 1 | KLS2-126-5.00-02 | Fabmicro:KLS2-126-5.00-2_Vertical
85 | XS2 | 1 | DM3AT-SF-PEJM5 | Fabmicro:HRS_DM3AT-SF-PEJM5
86 | XS3 | 1 | S2B-PH-K-S (LF)(SN) | Connector_JST:JST_PH_S2B-PH-K_1x02_P2.00mm_Horizontal
87 | XS4 | 1 | RJHSE-5381 | Fabmicro:AMPHENOL_RJHSE-5381
88 | XS5 | 1 | Conn_02x20_Odd_Even | Connector_PinHeader_2.54mm:PinHeader_2x20_P2.54mm_Vertical
89 | XS6 | 1 | S2B-PH-K-S (LF)(SN) | Connector_JST:JST_PH_S4B-PH-K_1x04_P2.00mm_Horizontal
90 | XS7 | 1 | USBA-2J | Fabmicro:USBA-2J
91 | XS10 | 1 | S4B-PH-K-S(LF)(SN) | Connector_JST:JST_PH_S4B-PH-K_1x04_P2.00mm_Horizontal
92 | XS12 | 1 | SJ-43516-SMT-BE | Fabmicro:CUI_SJ-43516-SMT-BE
93 | Y1 | 1 | 6MHz | Fabmicro:Crystal_SMD_7050-4Pin_7.0x5.0mm
94 | Y2 | 1 | 25 MHz | Fabmicro:Crystal_SMD_EuroQuartz_MT-4Pin_3.2x2.5mm

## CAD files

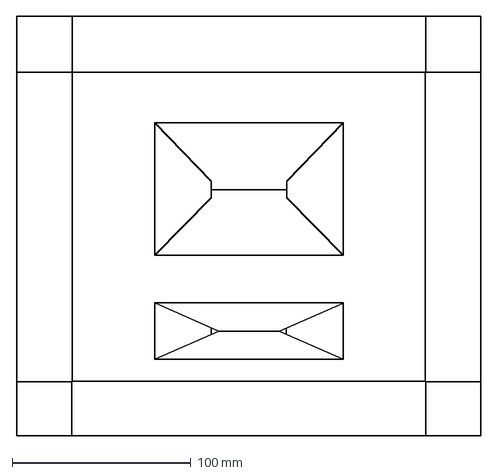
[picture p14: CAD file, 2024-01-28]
cadcam/karnix_cardboard_insert.dxf
259.8 x 234.8 mm

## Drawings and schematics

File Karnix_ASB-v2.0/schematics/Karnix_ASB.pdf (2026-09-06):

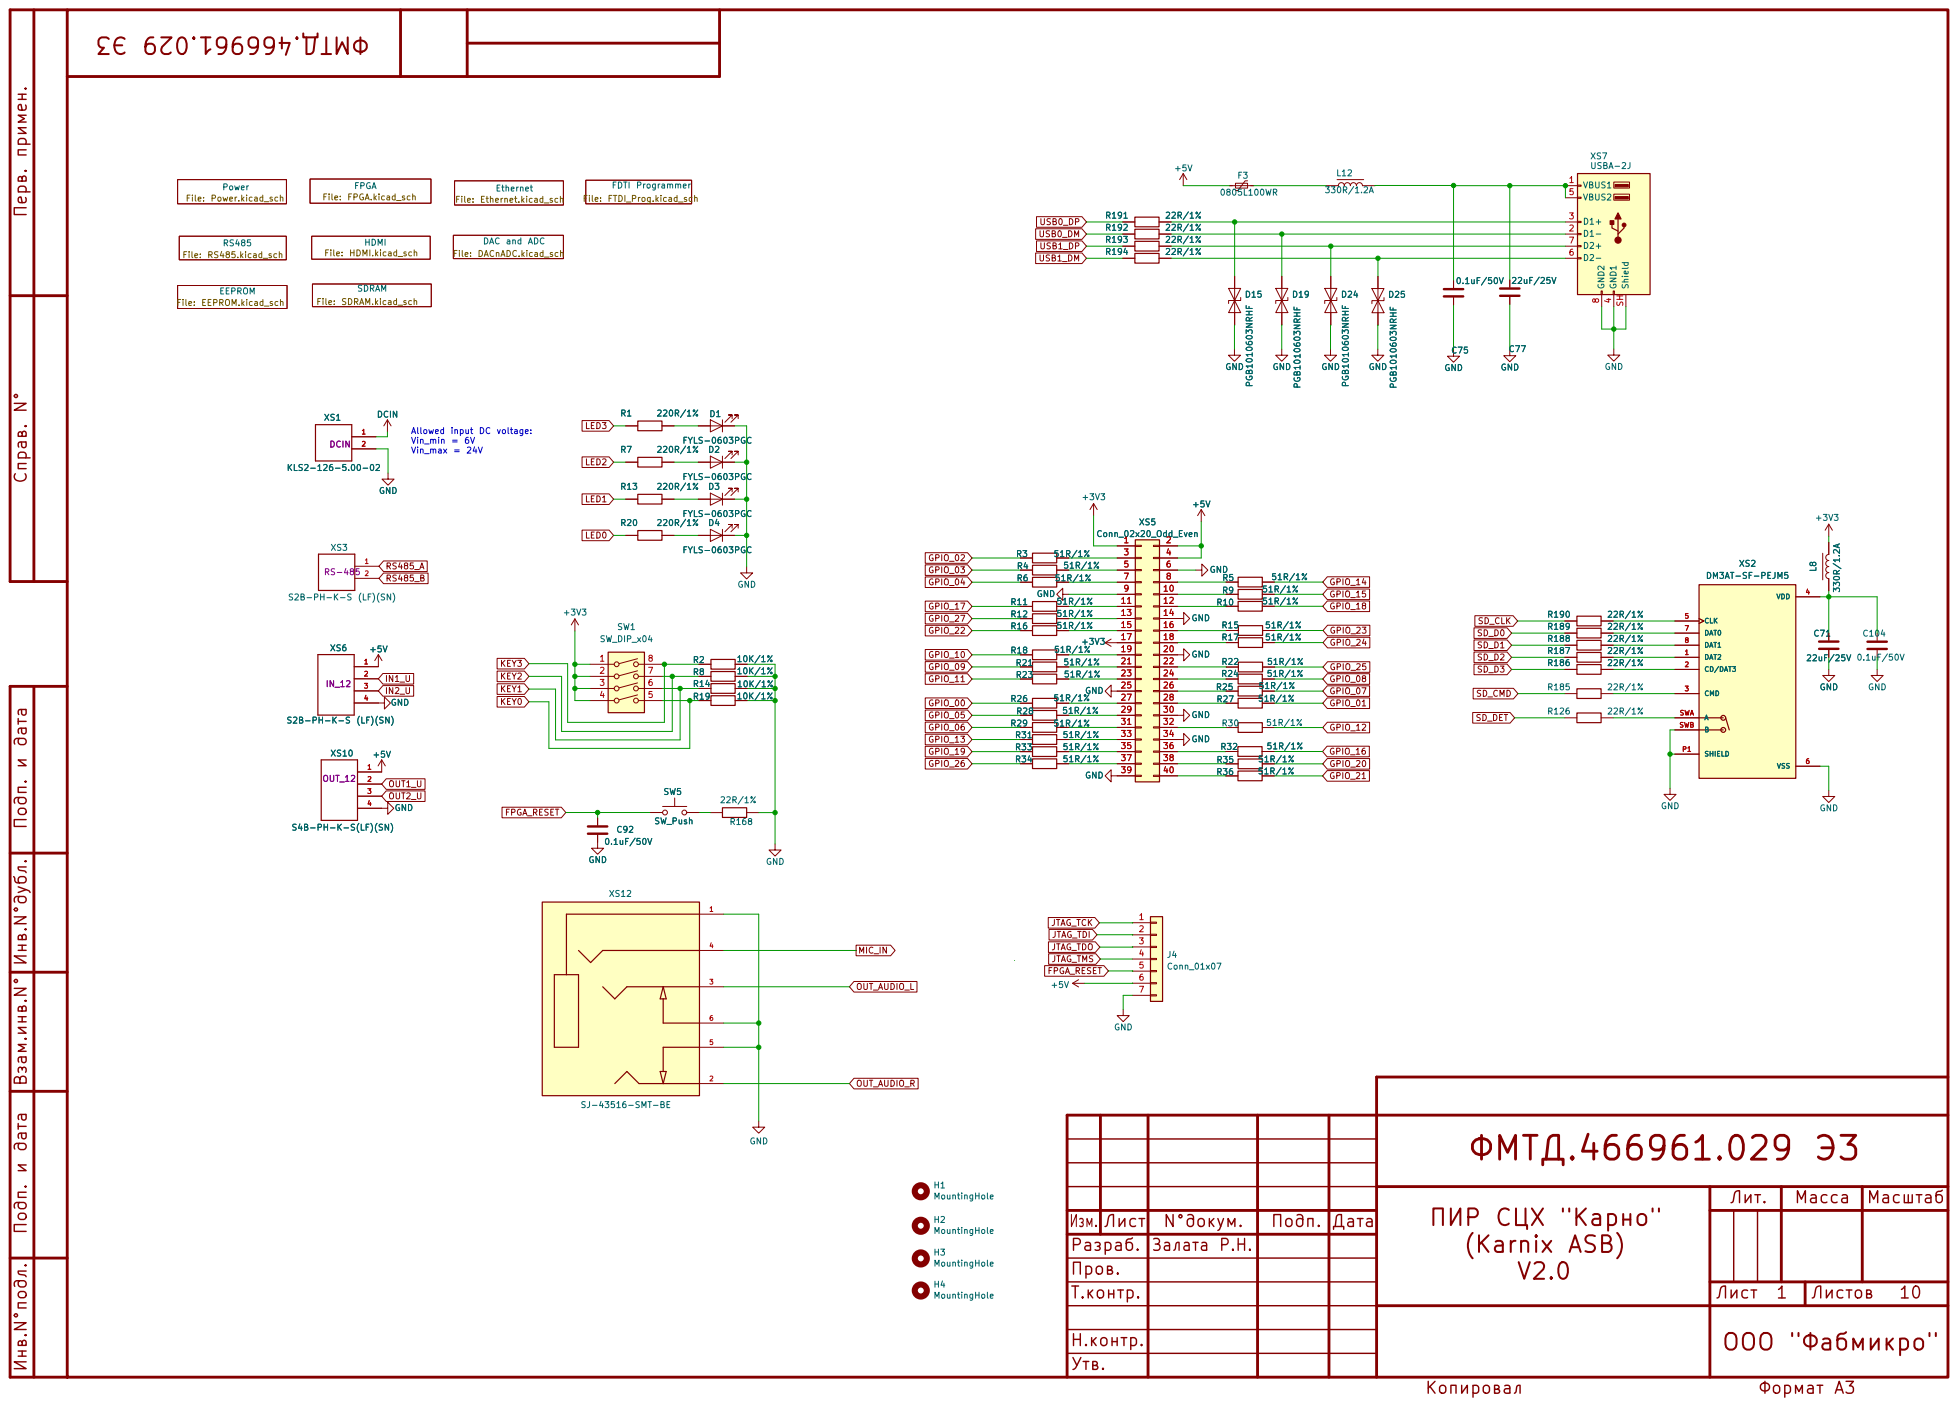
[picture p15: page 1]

Н.контр. Перв. примен. Подп. и дата Подп. и дата

FPGA
Ethernet File: Ethernet.kicad_sch SDRAM

FDTI Programmer File: FTDI_Prog.kicad_sch DAC and ADC

Allowed input DC voltage: Vin_min = 6V

S2B-PH-K-S (LF)(SN) RS-485 +5V GND
4+5V GND

Лист | | Подп.

Залата Р.Н.

Пров.
Т.контр.

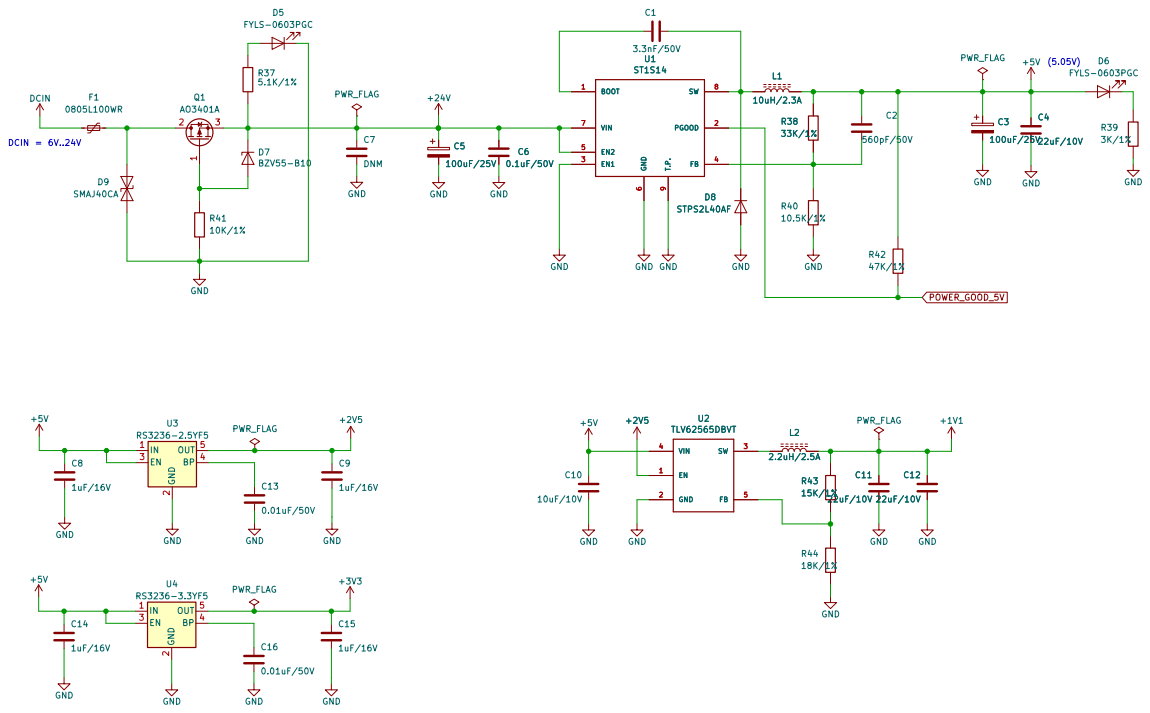
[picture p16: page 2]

Лист Подп. и дата Подп. и дата

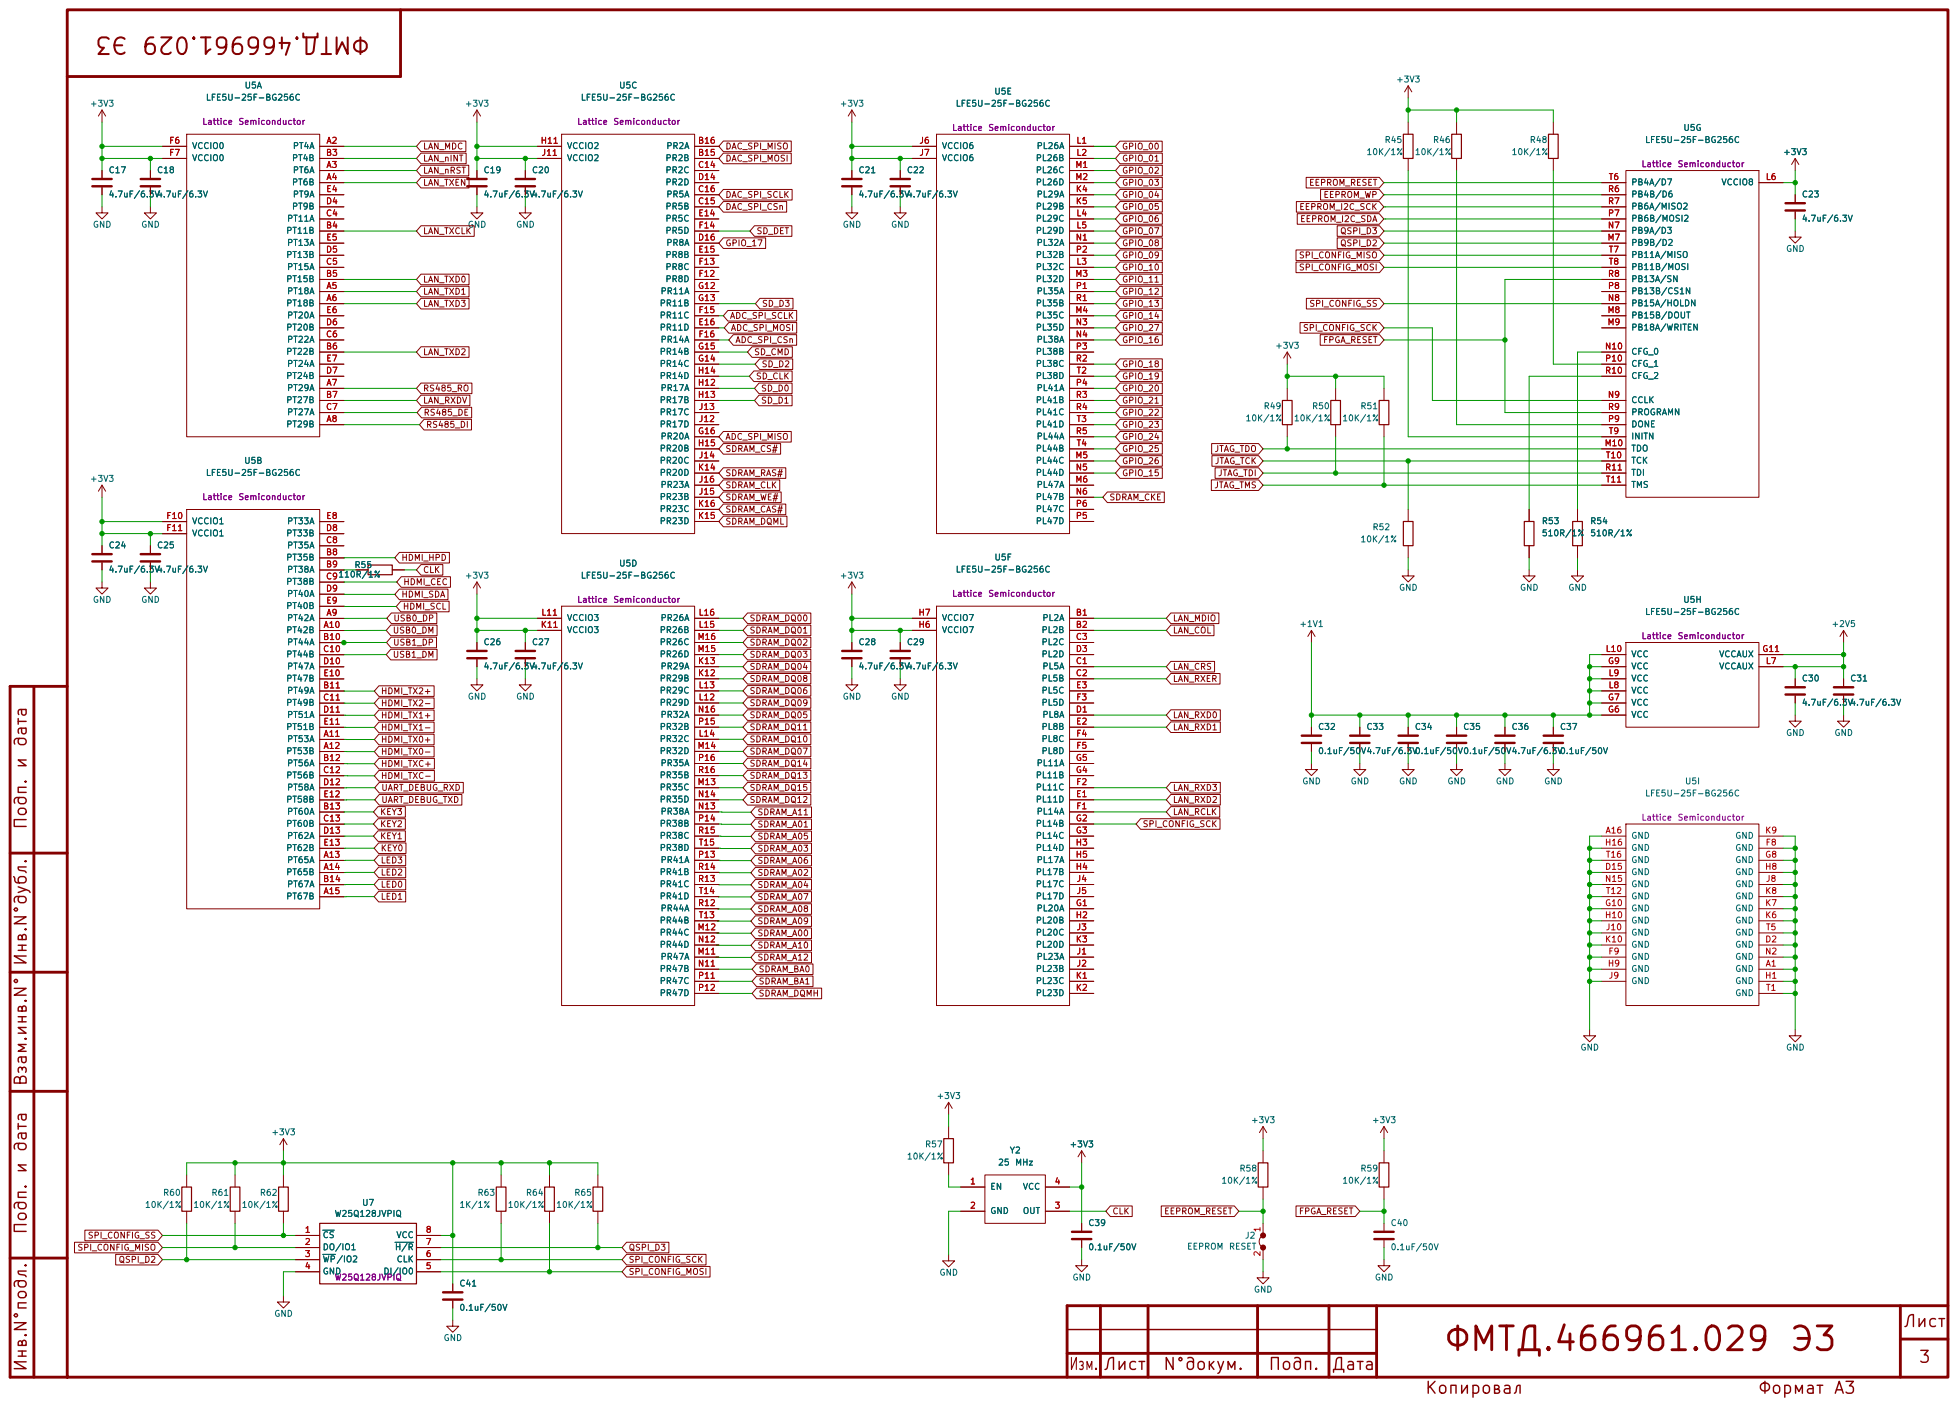
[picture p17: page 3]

Лист Подп. и дата Подп. и дата

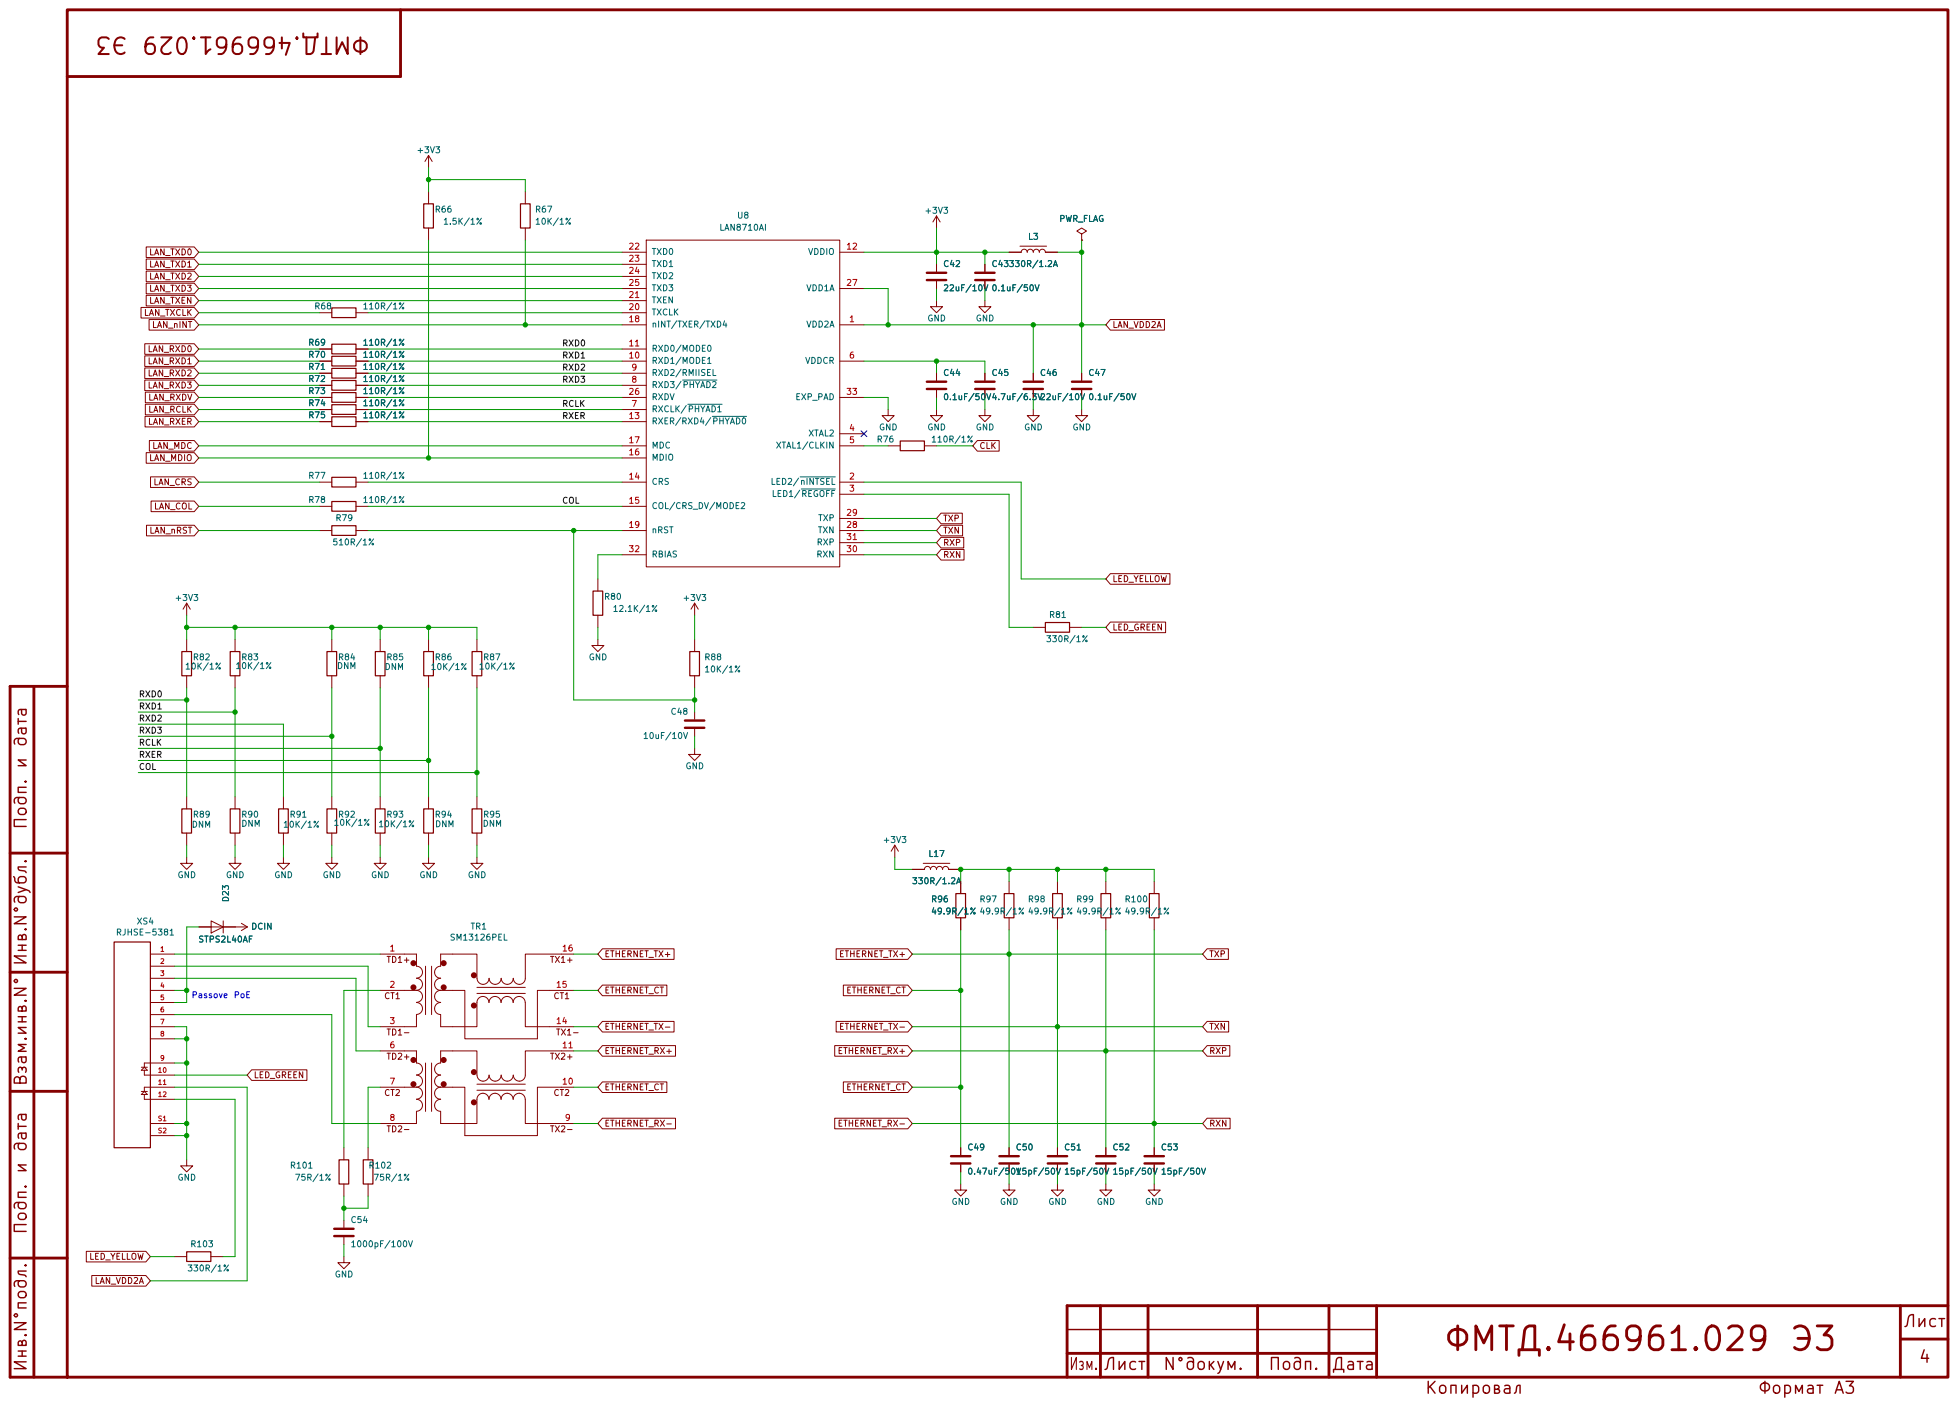
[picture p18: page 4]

Лист Подп. и дата Подп. и дата

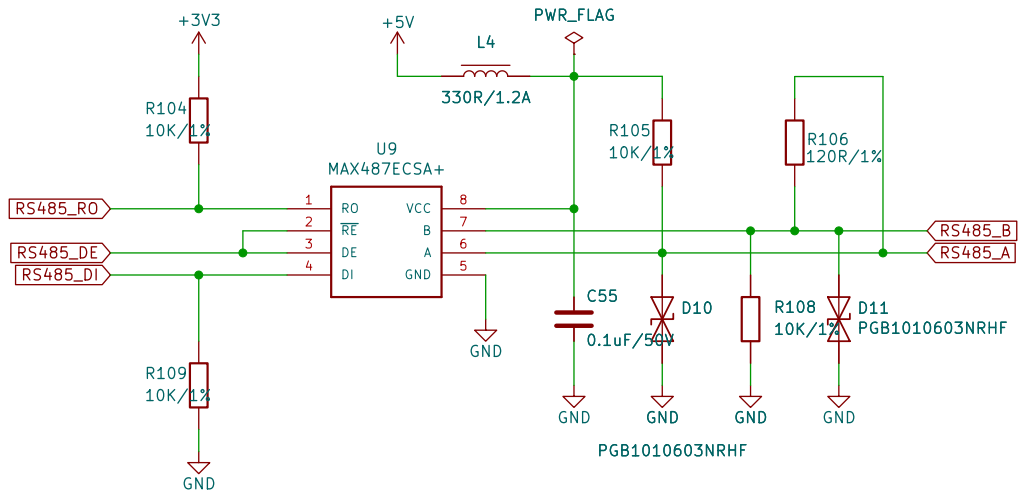
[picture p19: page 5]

Лист Подп. и дата Подп. и дата

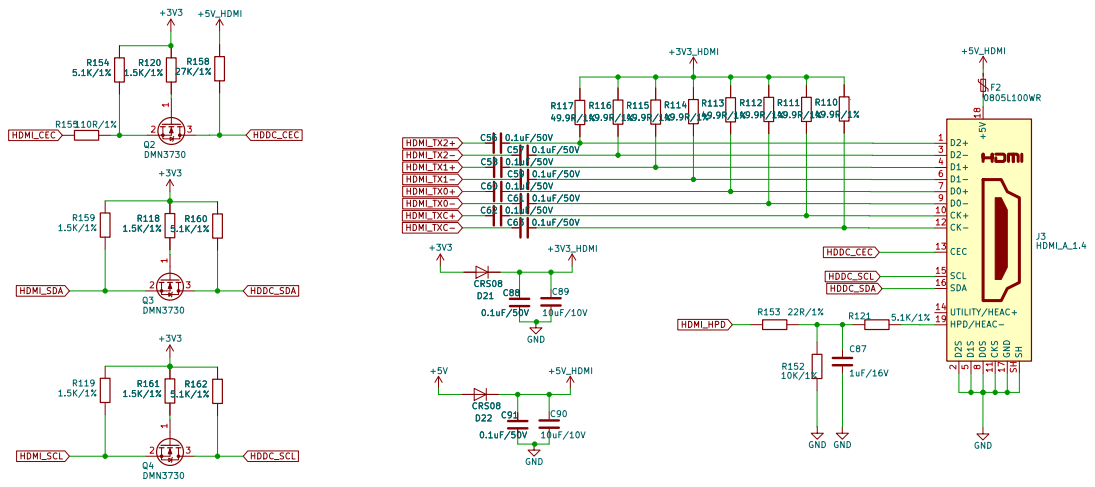
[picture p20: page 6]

8 D0- 9 CK+ 10 CKS 11 CK- 12 CEC 13 UTILITY/HEAC+ 14

Лист Подп. и дата Подп. и дата

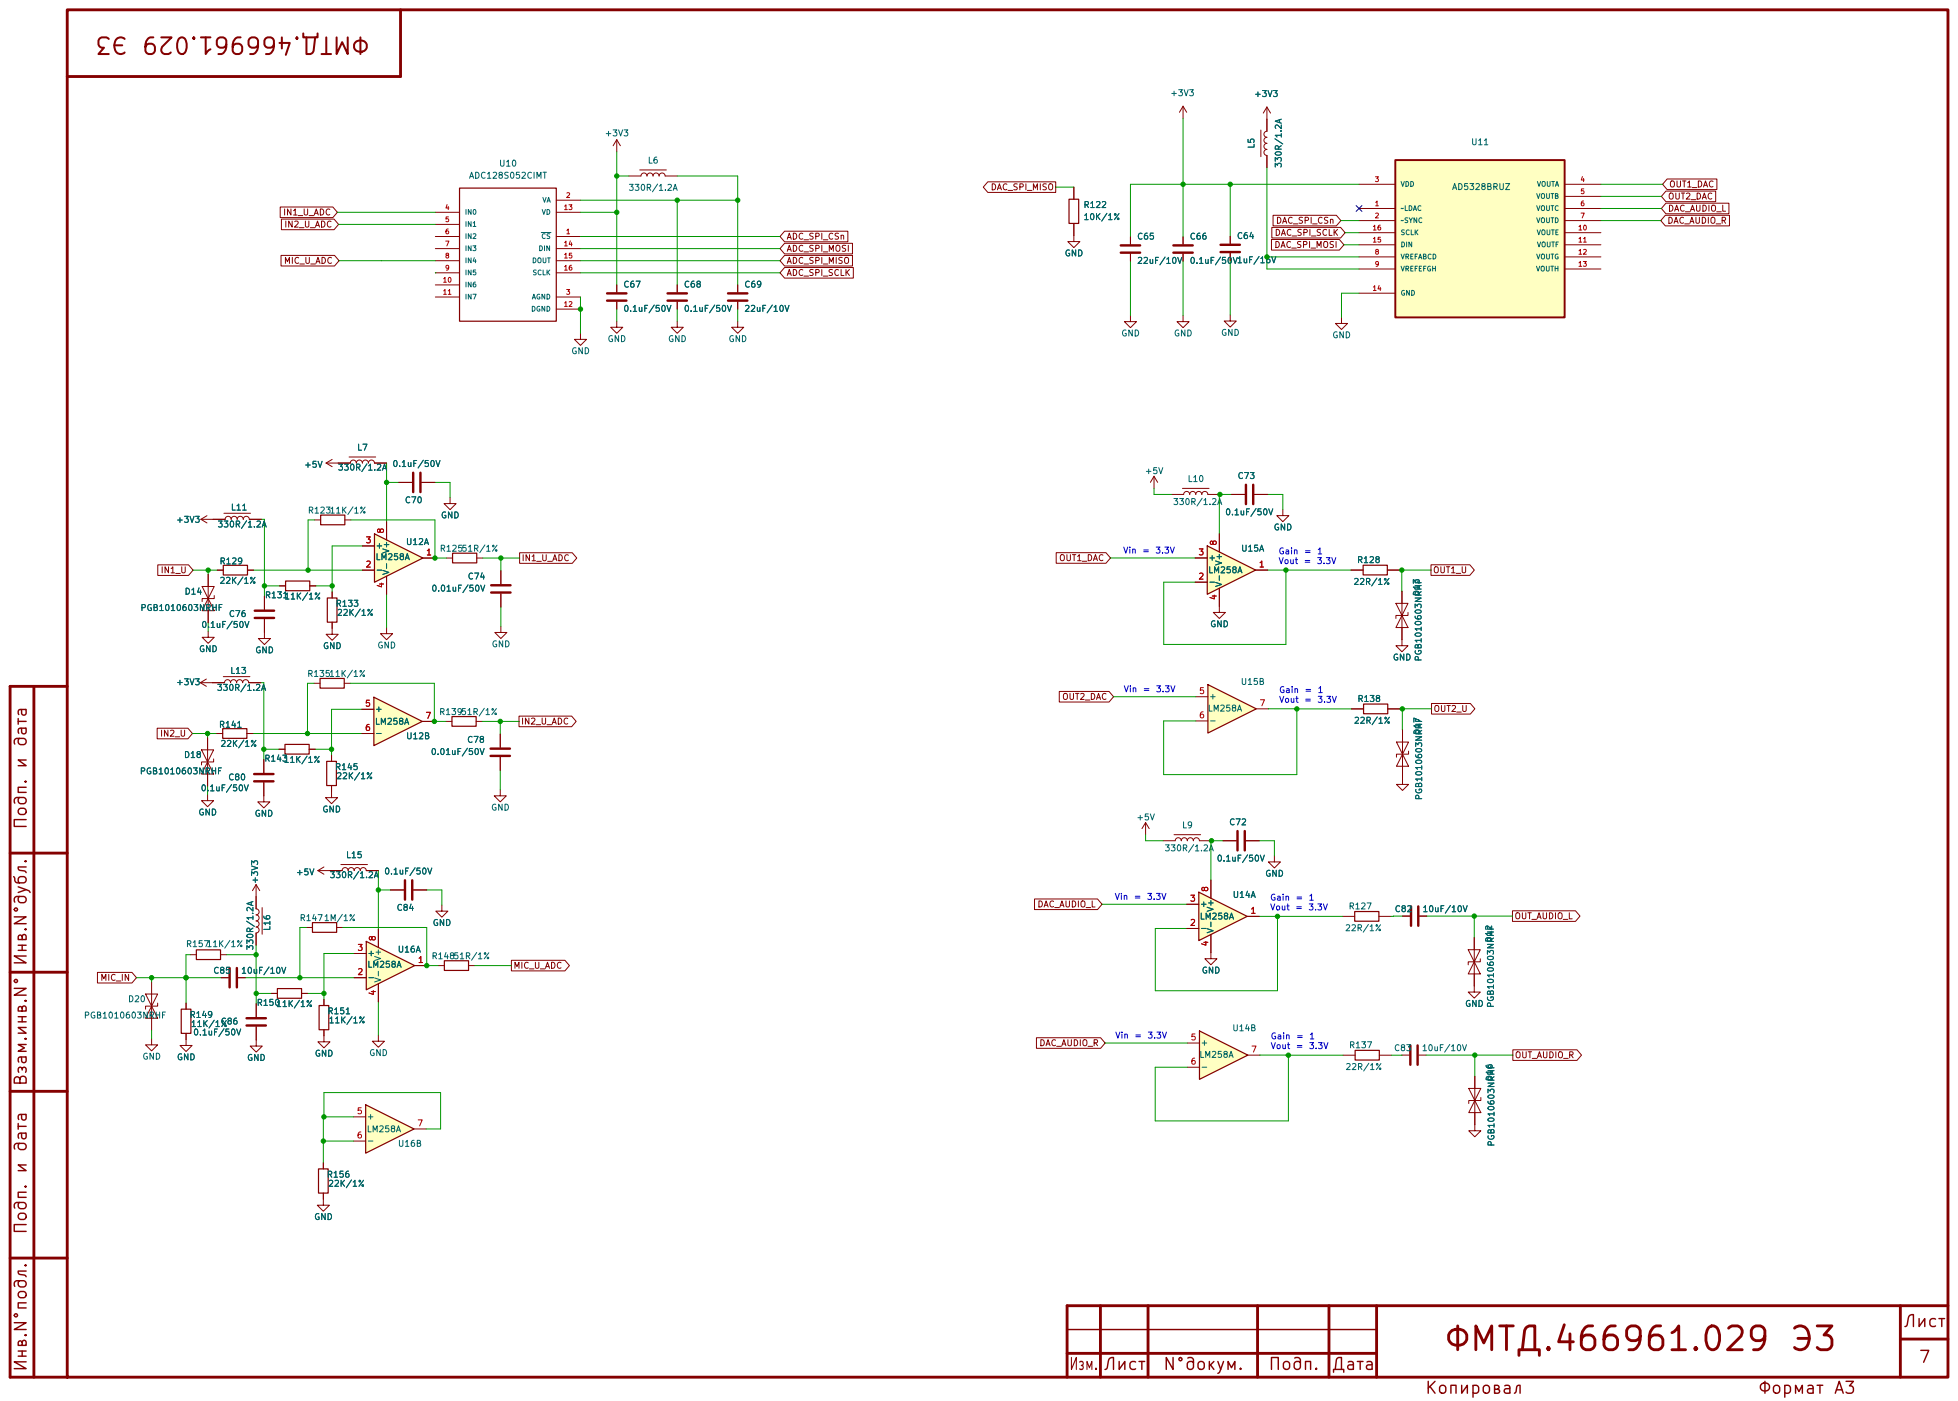
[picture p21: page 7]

Лист Подп. и дата Подп. и дата

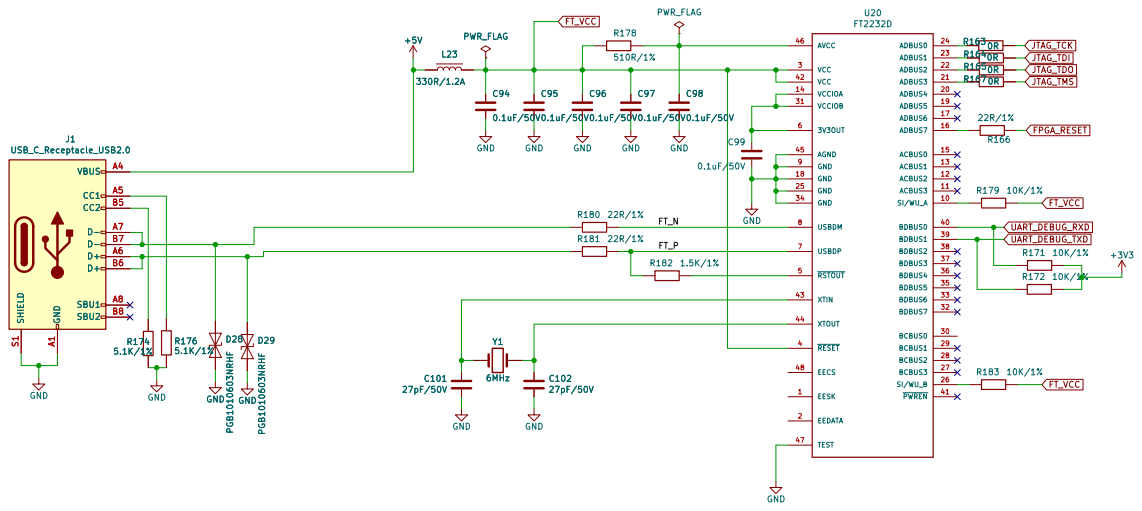
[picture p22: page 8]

VCCIOA 14 | R167 0R

SBU2 | B8 SHIELD S1

XTOUT 44

Лист Подп. и дата Подп. и дата

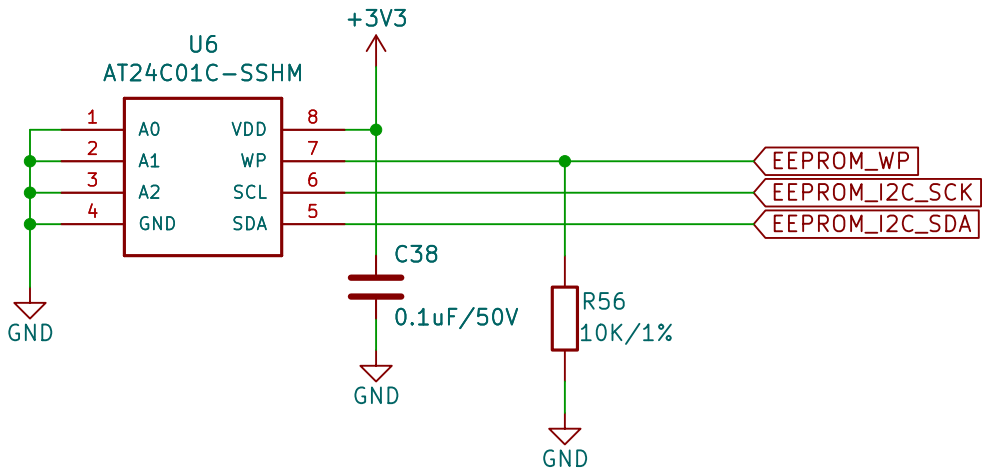
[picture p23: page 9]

Лист Подп. и дата Подп. и дата

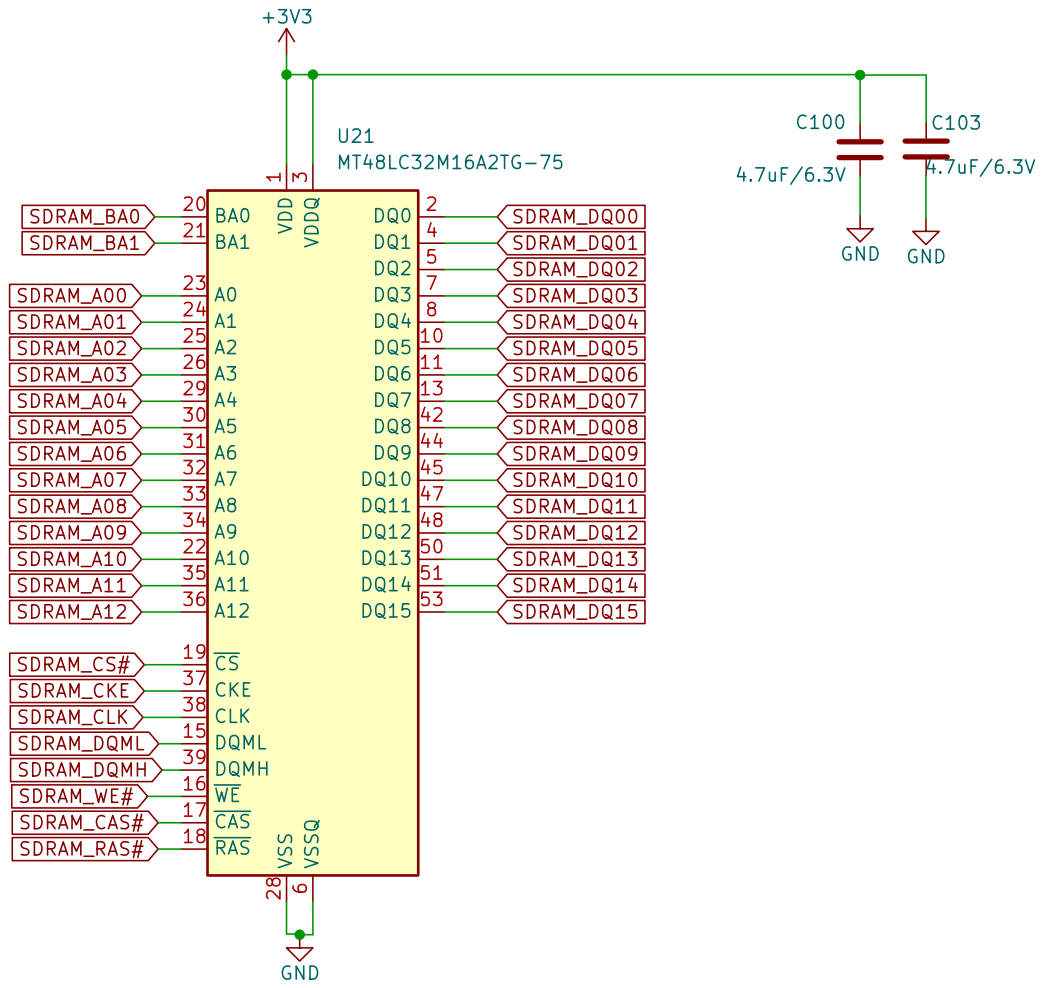
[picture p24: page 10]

6 DQ3 7 DQ4 8 DQ5 10 DQ6 11 DQ7 13 DQML 15 WE 16 CAS 17 RAS 18 CS 19 BA0 20 BA1 21

Лист Подп. и дата Подп. и дата

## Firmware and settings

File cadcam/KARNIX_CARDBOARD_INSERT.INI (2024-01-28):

[Technics_Laser_Data]
ModifyTechCFG=0
LayersNumber=2
ExportRows=1
ExportColumns=1
ExportRowSpace=0.00000
ExportColumnSpace=0.00000
ExportRowCW=0.00000
ExportColumnCW=0.00000
LogicOrgPositionX=711.11593
LogicOrgPositionY=595.75741
LogicOrgPositionZ=-9999999.00000
AtOnceExport=1
IsTwoLaserWorking=1
TableZeroPositionX=0.00000
TableZeroPositionY=0.00000
OutputTimes=1
DelayTime=0
FeedLength=0.00000
FeedSpeed=5.00000
FeedDelayTime=0
MinX=451.29981
MaxX=711.11593
MinY=360.95470
MaxY=595.75741
ChangeSerialNo=0
ArrayMinX=451.29981
ArrayMaxX=711.11593
ArrayMinY=360.95470
ArrayMaxY=595.75741
LayerColor_0=65280
LayerColor_1=255
ClipBoxPower=40.00000
ClipBoxPower2=40.00000
ClipBoxOffsetLen=2.00000
ClipBoxSpeed=25.00000
AlignMachineZPos=0.00000
RouteLength=0.00000
RoutePointNumber=0
OffsetLaserPower=0.00000
OffsetWorkSpeedPer=1.00000
ZHeightForLaserFocus=0.00000
OneWorkNeedTimes=2
TotalWorkTimes=0
[CoordSystem_0]
LogicOrgPosition1=711.11593
LogicOrgPosition2=595.75741
LogicOrgPosition3=-9999999.00000
SPLITBLOCK_NUMBER=2
SPLITBLOCK_NUMBER_0=0.00000
SPLITBLOCK_NUMBER_1=100000.00000
[CreateTechnicsCodeMgr]
PrjHasModifyCFG=1
[TechnicsLayers_65280]
TechnicsMode=TECHNICS_LASERCUT
LaserCutConnerPower=10.00000
LaserCutWorkPower=20.00000
LaserCutConnerPower2=30.00000
LaserCutWorkPower2=50.00000
LaserCutFrequency=20000
LaserCutOptimizePathType=1
LaserCutInnerToOuter=1
LaserCutInnerToOuter2=0
LaserCutDownToUpper=0
LaserCutBlockHeight=150.00000
LaserCutAutoSetPathDir=1
LaserCutCicleMinSegNumber=36
LaserCutDisperseLength=0.10000
LaserCutCloseGapLength=0.00000
LaserCutOverlapLength=0.00000
LaserCutAdjustForClose=1
LaserCutQXEnterLength=0.00000
LaserCutDelayMoveTime=0.00000
LaserCutOpenGZDelayTime=0.00000
LaserCutOpenLaserDelayTime=0.00000
LaserCutCloseLaserDelayTime=0.00000
LaserCutDelayTimeAfterCloseLaser=0.00000
LaserCutOneAxisBackLashLength=0.00000
LaserCutTwoAxisBackLashLength=0.00000
LaserCutBackLashAddSpaceLength=8.00000
LaserCutBlowGasType=0
LaserCutAheadBlowGasTimes=0.00000
LaserCutNoCloseGasTimes=0.00000
LaserCutSpeed=100.00000
LaserCutGWAcc=3000.00000
LaserCutGWTime=0.01000
LaserCutTrackSize=100
LaserCutLineLength=0.00000
SpaceCutLineLength=0.00000
bSpaceLineFirst=0
LaserCutAdjustMove=0
LaserCutAdjustMoveDelay=0.00000
LaserCutUpLen=0.00000
LaserCutCircleSpeedNum=6
LaserCutCircleSpeed0_MinR=0.00000
LaserCutCircleSpeed0_MaxR=0.55000
LaserCutCircleSpeed0_Speed=10.00000
LaserCutCircleSpeed1_MinR=0.55000
LaserCutCircleSpeed1_MaxR=1.05000
LaserCutCircleSpeed1_Speed=15.00000
LaserCutCircleSpeed2_MinR=1.05000
LaserCutCircleSpeed2_MaxR=1.55000
LaserCutCircleSpeed2_Speed=25.00000
LaserCutCircleSpeed3_MinR=1.55000
LaserCutCircleSpeed3_MaxR=2.05000
LaserCutCircleSpeed3_Speed=30.00000
LaserCutCircleSpeed4_MinR=2.05000
LaserCutCircleSpeed4_MaxR=3.05000
LaserCutCircleSpeed4_Speed=35.00000
LaserCutCircleSpeed5_MinR=3.05000
LaserCutCircleSpeed5_MaxR=4.05000
LaserCutCircleSpeed5_Speed=40.00000
GROUP_ROWS_0=1
GROUP_COLUMNS_0=1
GROUP_ROWSPACE_0=0.00000
GROUP_COLUMNSPACE_0=0.00000
GROUP_ROWCWSPACE_0=0.00000
GROUP_COLUMNCWSPACE_0=0.00000
GROUP_MINX_0=482.62319
GROUP_MAXX_0=680.22001
GROUP_MINY_0=391.47239
GROUP_MAXY_0=564.33566
[TechnicsLayers_255]
TechnicsMode=TECHNICS_LASERCUT
LaserCutConnerPower=35.00000
LaserCutWorkPower=45.00000
LaserCutConnerPower2=30.00000
LaserCutWorkPower2=50.00000
LaserCutFrequency=20000
LaserCutOptimizePathType=1
LaserCutInnerToOuter=1
LaserCutInnerToOuter2=0
LaserCutDownToUpper=0
LaserCutBlockHeight=150.00000
LaserCutAutoSetPathDir=1
LaserCutCicleMinSegNumber=36
LaserCutDisperseLength=0.10000
LaserCutCloseGapLength=0.00000
LaserCutOverlapLength=0.00000
LaserCutAdjustForClose=1
LaserCutQXEnterLength=0.00000
LaserCutDelayMoveTime=0.00000
LaserCutOpenGZDelayTime=0.00000
LaserCutOpenLaserDelayTime=0.00000
LaserCutCloseLaserDelayTime=0.00000
LaserCutDelayTimeAfterCloseLaser=0.00000
LaserCutOneAxisBackLashLength=0.00000
LaserCutTwoAxisBackLashLength=0.00000
LaserCutBackLashAddSpaceLength=8.00000
LaserCutBlowGasType=0
LaserCutAheadBlowGasTimes=0.00000
LaserCutNoCloseGasTimes=0.00000
LaserCutSpeed=100.00000
LaserCutGWAcc=3000.00000
LaserCutGWTime=0.01000
LaserCutTrackSize=100
LaserCutLineLength=0.00000
SpaceCutLineLength=0.00000
bSpaceLineFirst=0
LaserCutAdjustMove=0
LaserCutAdjustMoveDelay=0.00000
LaserCutUpLen=0.00000
LaserCutCircleSpeedNum=6
LaserCutCircleSpeed0_MinR=0.00000
LaserCutCircleSpeed0_MaxR=0.55000
LaserCutCircleSpeed0_Speed=10.00000
LaserCutCircleSpeed1_MinR=0.55000
LaserCutCircleSpeed1_MaxR=1.05000
LaserCutCircleSpeed1_Speed=15.00000
LaserCutCircleSpeed2_MinR=1.05000
LaserCutCircleSpeed2_MaxR=1.55000
LaserCutCircleSpeed2_Speed=25.00000
LaserCutCircleSpeed3_MinR=1.55000
LaserCutCircleSpeed3_MaxR=2.05000
LaserCutCircleSpeed3_Speed=30.00000
LaserCutCircleSpeed4_MinR=2.05000
LaserCutCircleSpeed4_MaxR=3.05000
LaserCutCircleSpeed4_Speed=35.00000
LaserCutCircleSpeed5_MinR=3.05000
LaserCutCircleSpeed5_MaxR=4.05000
LaserCutCircleSpeed5_Speed=40.00000
GROUP_ROWS_0=1
GROUP_COLUMNS_0=1
GROUP_ROWSPACE_0=0.00000
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

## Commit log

2023-10-03 Initial commit of Karnaugh Interactive Extendable ASIC Simulation Board AKA Karnix ASB-254 board. Features: - RPi3 form factor board with 40pin head connector - Lattice ECP5 25K FPGA, RISC-V ready - 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
    [DACnADC.kicad_sch, EEPROM.kicad_sch, Ethernet.kicad_sch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]
2023-10-03 Place and route DCIN to +5V power unit. Fix footprints and 3D models.
    [FTDI_Prog.kicad_sch, Karnix_ASB.kicad_pcb]
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2023-10-05 Fix power supply, use +3V3 rail instead
    [Ethernet.kicad_sch]
2023-10-05 Set schematics directory as default output for PDFs
2023-10-05 Rename transistor VT1 -> Q1
    [Power.kicad_sch]
2023-10-05 Rework HDMI wiring: - Connect SDL, SCL and CEC signals to FPGA through level converters - Separate HDMI power rails with diodes
    [FPGA.kicad_sch, HDMI.kicad_sch]
2023-10-05 Remove rudimentary referencies to old projects
    [DACnADC.kicad_sch, FTDI_Prog.kicad_sch, HDMI.kicad_sch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]
2023-10-05 Add passive PoE feature
    [Ethernet.kicad_sch]
2023-10-05 Fix transistor reference: VT1 -> Q4
    [HDMI.kicad_sch]
2023-10-05 Place and route power rails: +5V, +1V1 and +2V5. Use Int3 as +3V3 rail.
    [Karnix_ASB.kicad_pcb]
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2023-10-07 Fix EEPROM signal naming, move them to different location on FPGA
    [EEPROM.kicad_sch]
2023-10-07 Change HDMI connector footprint value layer to F.Fab
2023-10-07 Route HDMI and its environment
    [FPGA.kicad_sch, HDMI.kicad_sch, Karnix_ASB.kicad_pcb]
2023-10-07 Route FT2232D based programmer
    [Karnix_ASB.kicad_pcb]
2023-10-10 Route ADC channels IN1, IN2, IN3 and IN4.
    [FTDI_Prog.kicad_sch, Karnix_ASB.kicad_pcb]
2023-10-10 Route DAC1, DAC2, DAC_AUDIO_L, DAC_AUDIO_R and ADC_MIC channels
    [Karnix_ASB.kicad_pcb]
2023-10-10 Improve marker: move spot closer to pin 1, make front line shorter
2023-10-11 Move SRAM signals to some other pins on FPGA to ease routing
    [FPGA.kicad_sch]
2023-10-16 Cosmetic changes to ethernet schematics: refdes placement
    [Ethernet.kicad_sch]
2023-10-17 Fix ESD protection for Audio L/R signals
    [DACnADC.kicad_sch]
2023-10-17 Route JTAG and FPGA config. Fanout GPIO.
    [Karnix_ASB.kicad_sch]
2023-10-17 Rewire DAC and ADC to ease routing
    [FPGA.kicad_sch]
2023-10-18 Fix power rail to RS485 transciever
    [RS485.kicad_sch]
2023-10-18 Re-route SPI buses for ADC and DAC. Route RS485.
2023-10-18 Exchanges signals on DAC and ADC to ease routing
    [FPGA.kicad_sch]
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2023-10-19 Move GPIO_17 to different pin to ease routing
    [FPGA.kicad_sch]
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2023-10-20 Fix 3D model for USB connector
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2023-10-20 Update release date
    [DACnADC.kicad_sch, EEPROM.kicad_sch, Ethernet.kicad_sch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]
2023-10-20 Optimize component base
    [DACnADC.kicad_sch, EEPROM.kicad_sch, Ethernet.kicad_sch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]
2023-10-20 Add BoM file
    [Karnix_ASB_bom.csv]
2023-10-21 Add JTAG connector making onboard programmer FT2232D optional
    [FTDI_Prog.kicad_sch, Karnix_ASB.kicad_sch]
2023-10-21 Re-issue BoM
    [Karnix_ASB_bom.csv]
2023-10-21 Re-issue schematics PDF
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2023-10-24 Update board label and release date
    [DACnADC.kicad_sch, EEPROM.kicad_sch, Ethernet.kicad_sch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]
2023-10-24 Tapeout: issue gerber and drill files
    [Karnix_ASB-B_Cu.gbr, Karnix_ASB-B_Mask.gbr, Karnix_ASB-B_Paste.gbr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]
2023-10-24 Add "RISC-V Ready" logo and re-issue gerber files
    [Karnix_ASB-B_Cu.gbr, Karnix_ASB-B_Mask.gbr, Karnix_ASB-B_Paste.gbr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]
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2023-12-04 Bump up version to 1.1:
    - Move C90, C91 and D23 away from board edge to make automated assembly easier
    [DACnADC.kicad_sch, EEPROM.kicad_sch, Ethernet.kicad_sch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]
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2023-12-06 Increase current limiting resistors for LEDs lower brightness
    [Power.kicad_sch]
2023-12-06 Bugfixes and improvements:
    1. FT2232D VCCIOA and VCCIOB connect to 3V3OUT to provide 3.3V I/O
    2. Add SW5 button connected to FPGA_RESET as main reset signal
    3. Length match HDMI diff pairs
    [FTDI_Prog.kicad_sch, Karnix_ASB.kicad_sch]
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2023-12-10 Remove rudimentary signal names for Ethernet
    [Ethernet.kicad_sch]
2023-12-11 Save HDMI connector footprint in local library to allow changes to be made: add paste to through-hole pins
2023-12-11 Save USB type C connector footprint to local lib, add paste to through-hole pins
    [FTDI_Prog.kicad_sch]
2023-12-11 Substitute +3V3_ETH with +3V3 through ferrite bead
    [Ethernet.kicad_sch]
2023-12-11 Introduce recent schematic changes: update USB and HDMI footprints, +3V3_ETH to +3V3
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2024-01-15 Change GPIO current limiting resistors form 110R to 51R. Update modification date.
    [DACnADC.kicad_sch, EEPROM.kicad_sch, Ethernet.kicad_sch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]
2024-01-15 U21: remove comma character in value field, which is causing problems with assembly
    [SRAM.kicad_sch]
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2024-01-28 Add cardboard insert drawing and NC code for laser machine
    [karnix_cardboard_insert.dxf]
2024-02-01 Bump-up version to V1.2. Change R166 and R168 values to 22R (FPGA_RESET signal)
    [DACnADC.kicad_sch, EEPROM.kicad_sch, Ethernet.kicad_sch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]
2024-02-01 Add stencil for V1.0
    [Karnix_ASB-B_Paste.gbr, Karnix_ASB-F_Paste.gbr]
2024-05-19 Add QUCS simulation files for ADC prep circuits.
    [ADC_IN_1234.sch, ADC_IN_MIC.sch]
2024-05-27 Cosmetic changes to HDMI schematics
    [HDMI.kicad_sch]
2026-09-02 Library: Add missing C0805-Slim footprint
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2026-09-02 New board: Karnix ASB v2.0 (WIP)
    - Add programmabale CLK for NOR flash
    - Add SD-card slot
    - Remove ADC3,4 and DAC2,3 ports.
    - Use single JST connector for all ACD and same for all DAC signals.
    TODO:
    - Add USB type A connector.
    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
    [DACnADC.kicad_sch, EEPROM.kicad_sch, Ethernet.kicad_sch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]
2026-09-02 Add USB0 and USB1 ports to schematics
    [Karnix_ASB.kicad_sch]
2026-09-02 Library: Add missing 3D model for SD-card connector DM3AT-SF-PEJM5
2026-09-02 Fix wiring of USB connector
    [Karnix_ASB.kicad_sch]
2026-09-02 Library: Add symbol, footprint and 3D model for USB Type A Stacked connector
2026-09-02 Use newly added USB type A Stacked connector in schematics
    [Karnix_ASB.kicad_sch]
2026-09-02 Change four input buttons to one 4xDIP switch, re-order KEYs and LEDs
    [Karnix_ASB.kicad_sch]
2026-09-02 Fixed USB DM/DP series resistors wiring
    [Karnix_ASB.kicad_sch]
2026-09-03 V2.0 routing work in progress:
    Completed parts:
    1. SD-card
    2. USB type A connector
    [FPGA.kicad_sch, Karnix_ASB.kicad_pcb, RS485.kicad_sch]
2026-09-03 Add SDRAM (8M x 4 x 16), remove SRAM
    [FPGA.kicad_sch, Karnix_ASB.kicad_sch, SDRAM.kicad_sch]
2026-09-05 SDRAM routing complete.
    A number of SDRAM_Ax and SDRAM_DQx singnals were swapped to ease routing.
    [FPGA.kicad_sch, Karnix_ASB.kicad_pcb, Karnix_ASB.kicad_sch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]
2026-09-06 Increase capacitance for power lines (0.1uF -> 4.7uF)
    [DACnADC.kicad_sch, EEPROM.kicad_sch, Ethernet.kicad_sch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]
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2026-09-06 Release photoplots in Gerber format
    [Karnix_ASB-B_Cu.gbr, Karnix_ASB-B_Mask.gbr, Karnix_ASB-B_Paste.gbr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]
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2026-09-06 Release PnP files in CSV format
    [Karnix_ASB-bottom-pos.csv, Karnix_ASB-top-pos.csv]
2026-09-06 Release BoM file in CSV format
    [Karnix_ASB.csv]
